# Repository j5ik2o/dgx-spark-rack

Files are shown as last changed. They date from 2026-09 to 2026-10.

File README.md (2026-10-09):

# DGX Spark Rack

DGX Spark本体とACアダプターを置く、3Dプリント用ラックです。**4台専用ラックへの再設計を始めています。** 2列×2段とラック内の交換可能なスイッチ置き場を前提に、リング接続・スイッチ接続の配線は手持ち40cmと当初案の50cmを比較します。[新設計の条件](models/spark-rack/docs/4台専用ラックの設計条件.md)と[従来データの保全](archive/spark-rack-modular-20261009/README.md)を参照してください。

136部品案は不採用です。現在は`mise run overview:spark-rack`で[枠を小型化し、電源4個も内蔵する全体構想](models/spark-rack/docs/凹凸の接合試験片と次案.md)を確認できます。試験片の印刷は後回しです。`mise run joint:spark-rack`は短い接合試験片だけを生成します。梁の取付穴とスイッチ支持板は実測後に設計します。`mise run layout:spark-rack`は[配置の参考](models/spark-rack/docs/仮配置の確認.md)、`mise run build`は従来の3モデル用です。正本は引き続き各モデルの`source/`です。

## 何を編集するか

| 現行モデル | 正本（SSoT） | 最初に開く案内 |
|---|---|---|
| Spark本体ラック | [source内のPythonコードと寸法定義](models/spark-rack/source/) | [本体ラック](models/spark-rack/README.md) |
| ACアダプターラック | [source内のPythonコードと寸法定義](models/adapter-rack/source/) | [アダプターラック](models/adapter-rack/README.md) |
| ファンコンケース | [source内のPythonコード（冒頭に寸法定義）](models/fan-controller/source/freecad_fan_controller.py) | [ファンコンケース](models/fan-controller/README.md) |

3モデルともPythonを正本とし、FCMacroを実行入口にします。ファンコンケースは[共通ドックで両ラックへ取り付ける設計](models/fan-controller/docs/ラックへの取り付け.md)です。実物の取付・強度は未検証です。

## フォルダは用途で分ける

| フォルダ | 入れるもの | 正本として編集するか |
|---|---|---|
| `models/` | 現行モデルの設計コード・CAD正本、参照仕様、モデル別の説明 | `source/`を編集する。`reference/`は購入品の根拠資料 |
| `build/` | 現行モデルから作ったFCStd・STEP・STL・画像・検査結果 | 編集しない。正本から出力する |
| `print-projects/` | スライサーの3MF。配置、材料、ブリム等の印刷設定 | 印刷条件の変更先。形状の正本ではない |
| `archive/` | 旧アダプタースタンド、採用をやめた印刷配置、過去の生成結果 | 現行設計には使わない |
| `tools/` | 複数モデルで使うCAD補助・検査ツール | 共通処理を変更するときだけ編集 |
| `docs/` | リポジトリ全体の運用ルール | 運用を変更するときに編集 |

`exports/`、`design/`、`scripts/`と直下のFCStdは廃止し、上の用途に応じて移動しました。旧スタンドは[archive/adapter-stand-v1](archive/adapter-stand-v1/README.md)にまとめています。

## コマンドで生成する

```sh
mise trust
mise run doctor
mise run build                 # 全モデルのCAD・STL・検査結果
mise run 3mf:prototype:fan-controller     # ケースのCADから、部品別3MFまで生成
```

全モデルの3MFは `mise run 3mf:prototype`。部品・個数の指定と生成先は[タスクランナーの案内](docs/タスクランナー.md)を参照してください。3MFはX1C向けPLA試作設定で、スライス前の状態です。

## レビューを始める

1. 上の表で対象モデルを選び、その案内を開く。
2. `source/`で設計を確認する。各モデルの案内に記載した生成マクロをFreeCADで実行する。
3. `build/<モデル名>/`で形状と検査結果を確認する。印刷設定を確認するときだけ[print-projects](print-projects/README.md)を開く。

生成物は各モデルとも `build/<モデル名>/<実行ID>/` に保存し、Gitには含めません。詳細は[正本と生成物の管理](docs/設計コードと生成物の管理.md)を参照してください。

印刷部品には、外周の面取りとフィレットを設計コードから適用します。[部品別の処理と保護する接合部](docs/面取りとフィレット.md)を参照してください。

## ライセンス

[Apache License 2.0](LICENSE)

Copyright 2026 IDEO PLUS LLC

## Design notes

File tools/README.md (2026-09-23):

# 共通ツール

モデル固有の形状や寸法はここに置きません。現行モデルの設計は [../models/](../models/) を参照してください。

- `cad/freecad_features.py`：拘束付きスケッチと加工の共通処理。
- `cad/check_stl.py`：バイナリSTLの閉じた形状、接続成分、体積、造形寸法を検査。
- `cad/edge_finishing.py`：対象面の凸稜線を選択し、面取り・開口フィレット・寸法変更時の再計算を実施。
- `cad/freecad_mcp.py`：FreeCAD MCPへPythonコードを渡す補助ツール。

- `tasks/cad.py`：miseから呼ぶCAD・3MF生成タスク。
- `tasks/cad_worker.py`：FreeCAD専用プロセスの実行入口。

## ライセンス

[Apache License 2.0](../LICENSE)

Copyright 2026 IDEO PLUS LLC

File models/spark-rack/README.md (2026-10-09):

# Spark本体ラック

**136部品案は不採用です。** 現在は[枠を小型化し、電源4個も内蔵する全体構想](docs/凹凸の接合試験片と次案.md)を検討しています。`mise run overview:spark-rack`で新旧比較の画面を生成します。試験片の印刷は後回しです。`joint:spark-rack`または`structure:spark-rack`は短い試験片だけを生成し、全体の造形用データは生成しません。

[設計条件](docs/4台専用ラックの設計条件.md)と[配置参考](docs/仮配置の確認.md)を参照してください。配置参考の下段高さと制御ケース位置は次案の共通定義へそろえ、未測定の横ずれは製造穴に採用しません。

以下は従来の連結式ラックの操作案内です。[従来データは一式保全済み](../../archive/spark-rack-modular-20261009/README.md)です。

**正本は `source/` のPython設計コードと寸法定義です。**

| 用途 | ファイル |
|---|---|
| 寸法・隙間 | [spark_rack_parameters.py](source/spark_rack_parameters.py) |
| 部品形状・組立配置 | [freecad_spark_rack.py](source/freecad_spark_rack.py) |
| FreeCADで生成 | [run_spark_rack.FCMacro](source/run_spark_rack.FCMacro) |
| 検査 | [validate_spark_rack.py](source/validate_spark_rack.py) |

出力先は `build/spark-rack/<実行ID>/`。FCStd・STEP・STL・画像・検査結果・manifestを保存します。旧FCStdを読み込まず、Pythonの形状定義から生成します。生成FCStdの寸法表は生成時の記録で、編集によって形状が連動するものではありません。変更はPythonへ反映して再生成してください。

現在の接合隙間は0.30mm、ファンは140mmです。0.20mmへの変更は今回のコード移行に含みません。実物の強度・冷却は別途確認が必要です。

[印刷設定](../../print-projects/README.md) と [移行前データ](../../archive/spark-rack-fcstd-v1/README.md) は別管理です。

新版の側板にはファンコン用M4穴を追加しています。`controller_dock.stl` を介して、各ファンのケースをラック外側へ固定します。[取付位置と金具](../fan-controller/docs/ラックへの取り付け.md)を参照してください。旧側板を使用する場合は追加穴加工または新版への交換が必要です。

前面は幅210mmのフレームと外形を揃え、側枠と同じ幅12mmの外周をファン保持部へ一体化しています。高さ162mmの前面枠は、170mmの側枠に対して上下4mmずつ内側です。ファン取付穴・送風開口・保持部の接合位置は維持しています。

## ライセンス

[Apache License 2.0](../../LICENSE)

Copyright 2026 IDEO PLUS LLC

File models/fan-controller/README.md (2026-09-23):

# ファンコンケース

**正本は [source/freecad_fan_controller.py](source/freecad_fan_controller.py) です。** 冒頭の寸法・設定と、それに続く形状コードを編集します。

| 用途 | ファイル |
|---|---|
| 寸法・形状の編集 | [freecad_fan_controller.py](source/freecad_fan_controller.py) |
| FreeCADで生成を実行 | [FanControllerCase.FCMacro](source/FanControllerCase.FCMacro) |
| FCStd・STEP・STL・検査結果の出力 | [build_fan_controller.py](source/build_fan_controller.py) |
| プレビュー画像の生成 | [render_preview.py](source/render_preview.py) |

FreeCADでマクロを実行すると、`build/fan-controller/<実行ID>/` に新規出力します。FCStdとSTEPは組立座標、STLは本体を底面下・蓋を天面下・独立押さえを平置きにして原点へ接地した座標です。`manifest.json` が成功状態であることを確認してください。出力はGit管理対象外です。

## 基板の固定：本体側のねじ留め押さえ

試作で折れた蓋の薄板（厚さ0.9mm・長さ15.07mm）は廃止しました。厚さ3mmの独立押さえを本体の着座ポケットにねじ留めし、基板の縁へ0.8mm掛けます。基板の受け位置・高さは従来どおりです。ねじの締付けは着座面で受け、基板上面には0.20mmの遊びを残します。基板への穴あけは不要です。

| 部品 | ケース1組の必要数 |
|---|---:|
| `CaseBody.stl` | 1 |
| `CaseLid.stl` | 1 |
| `PCBClamp.stl` | 4（同形。反対側は180度回転して組み付け） |
| 呼び径2mm×8mmの樹脂用ねじ | 蓋4本＋押さえ4本＝8本 |

押さえ用ねじ頭は外径4mm以下・高さ1.6mm以下を想定しています。下穴1.6mmは仮値で、使用するねじと印刷材料で確認してください。M4ラック用ねじとは別です。

組立は、基板を受けまで入れる → 押さえ4個を着座面に置く → 各1本のねじで固定 → 蓋を取り付ける、の順です。蓋ねじの位置を変更しているため、本体・蓋は今回生成した組を使います。旧版との混用はできません。

CADでは単一ソリッド、基板・本体・蓋・端子台との干渉、着座面、ねじ頭・ドライバーの空間、上からの着脱を検査します。基板縁の部品・はんだと押さえの実物適合、折れにくさ、繰り返し締結の強度は未検証です。既定の3MF生成は各種類1個なので、押さえ4個を作る場合は `mise run 3mf:prototype:fan-controller -- --part PCBClamp --copies 4` を使います。

プレビューはFreeCAD対応Pythonとmatplotlib・numpyのある環境で `render_preview.py <今回の出力フォルダ>` を実行します。現在の正本から生成するため、同じ設計版の出力先を指定してください。画像は補助資料で、形状の正本ではありません。

元の `designs/fan-controller/FanControllerCase.FCMacro` の形状コードはそのままPythonへ移しました。元マクロ、既存プレビュー、過去の検査記録は [取り込み時のアーカイブ](../../archive/fan-controller-import/README.md) に保全しています。元worktreeは変更していません。今後の編集先はこの `source/` です。

USB-Cは今回の実測値に反映済みです。端子台の逃げ、ファン・温度センサー開口には未修正の箇所が残ります。実物の適合・操作性は未検証です。

## ラックへの取り付け

ケース底部の外側に取付耳を設け、M3穴ピッチ92mmで共通ドックへ固定します。箱本体81.4×39.4mmに対し、耳を含む長さは100mmです。本体ラックは `controller_dock.stl`、アダプターラックは `accessory_plate.stl` として同じドック形状を出力します。[取付方法と必要金具](docs/ラックへの取り付け.md)を参照してください。

## ライセンス

[Apache License 2.0](../../LICENSE)

Copyright 2026 IDEO PLUS LLC

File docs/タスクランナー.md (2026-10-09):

# CADと3MFをコマンドで生成する

`mise`、FreeCAD、Bambu Studioを使います。macOSの `/Applications` にインストールした環境で動作確認しています。初回はリポジトリのルートで `mise trust`、続けて `mise run doctor` を実行します。

## 使うコマンド

| コマンド | 出力 |
|---|---|
| `mise run build` | 全3モデルのFCStd・STEP・STL・検査結果・manifest。ラックは配置画像も生成 |
| `mise run build:spark-rack` | 本体ラックだけを生成・検査 |
| `mise run build:adapter-rack` | アダプターラックだけを生成・検査 |
| `mise run build:fan-controller` | ケースだけを生成・検査 |
| `mise run 3mf:prototype` | 全3モデルをCADから再生成し、部品別の3MFを作成 |
| `mise run 3mf:prototype:spark-rack` | 本体ラックのCADと3MFを生成 |
| `mise run 3mf:prototype:adapter-rack` | アダプターラックのCADと3MFを生成 |
| `mise run 3mf:prototype:fan-controller` | ケースのCADと3MFを生成 |
| `mise run test` | タスクの入力検査・失敗時の扱いを検査 |

**`3mf:prototype` はCAD生成を含みます。先に `build` を実行する必要はありません。** 全モデルのタスクは順番に実行します。FreeCADのGUIが起動しますが、通常終了後に閉じます。途中で失敗した場合はタスクもエラーで終了します。

生成先は次の2か所です。毎回新しい実行IDを使い、既存ファイルは上書きしません。

- CAD：`build/<モデル名>/<実行ID>/`
- 3MF：`print-projects/<モデル名>/<用途>/generated/<実行ID>/`

どちらも自動生成フォルダはGit管理対象外です。3MF側のmanifestに、元のCAD実行ID・STLハッシュ・プロファイルのハッシュ・検査結果を保存します。既存の手調整済み3MFはそのまま保全します。生成後に調整して採用した3MFは、`generated/` の外の同じ用途のフォルダへ別名保存してください。

## 部品と個数を指定する

既定は**試験片を含む全種類を、1種類につき1個ずつ別の3MF**にします。組立1台分の部品数ではありません。必要な数は各モデルの部品表で確認してください。ピンと大型部品は別ファイルになります。

```sh
# ケースの蓋を2個。CADは先に自動生成する
mise run 3mf:prototype:fan-controller -- --part CaseLid --copies 2

# 既に生成・検査したSTLを使う（日時部分は実際の出力先に置き換える）
mise run 3mf:prototype:spark-rack -- --build-dir build/spark-rack/実行ID --part locking_pin --copies 6
```

`--build-dir` は指定モデルの成功した出力だけを受け付けます。設計コードや生成物のハッシュが変わっていれば停止するので、再生成してください。失敗した実行のmanifestは `failed` になります。

## 試作用3MFの印刷設定

共通の[PLA試作用プロファイル](../print-projects/profiles/pla-prototype.json)を使います。プリンターはX1 Carbon・0.4mmノズル、材料はBambu PLA Basic、プレートはTextured PEI、積層0.20mm、壁4周、インフィル20%、外側ブリム5mmです。Bambu Studioに同梱された設定を継承するため、アプリ更新で既定値が変わることがあります。生成した3MFに実際の設定が保存されます。

これは**スライス前のプロジェクト3MF**です。G-code生成・プリンター送信は行いません。Bambu Studioで開いて、必要なサポート・向き・プレート配置・個数・実際のフィラメント割り当てを確認してからスライスしてください。本番素材への変更は別途必要です。CLIの自動配列は使いますが、自動回転は無効にしてCADで設定した造形方向を保持します。

3MF生成にはBambu Studio公式の `--load-settings`、`--load-filaments`、`--export-3mf` を使っています。[公式CLI説明](https://github.com/bambulab/BambuStudio/wiki/Command-Line-Usage)

## インストール先が異なる場合

次の環境変数で変更できます。互換性のあるFreeCADのPython・ライブラリを組にして指定してください。GUIを利用するため、ディスプレイのない環境では追加の対応が必要です。

| 変数 | 既定値 |
|---|---|
| `FREECAD_PYTHON` | `/Applications/FreeCAD.app/Contents/Resources/bin/python` |
| `FREECAD_LIB` | `/Applications/FreeCAD.app/Contents/Resources/lib` |
| `BAMBU_STUDIO` | `/Applications/BambuStudio.app/Contents/MacOS/BambuStudio` |
| `BAMBU_PROFILES` | `/Applications/BambuStudio.app/Contents/Resources/profiles/BBL` |

`mise`を使わない場合も `python3 tools/tasks/cad.py build spark-rack` や `python3 tools/tasks/cad.py 3mf fan-controller --purpose prototype` で同じ処理を実行できます。

## 4台専用ラックの仮配置を生成する

136部品案は不採用です。`mise run joint:spark-rack`または`structure:spark-rack`は、`build/spark-rack/joint-coupons/<実行ID>/`へ短い接合試験片だけを生成します。[次案と試験片](../models/spark-rack/docs/凹凸の接合試験片と次案.md)を参照してください。旧案の明示的な履歴再生成は`python3 archive/spark-rack-structure-rejected-20261009-172152/source/build_four_node_structure.py --historical`で、出力を`archive/build-history/`へ分けます。旧案を印刷しません。

4台専用ラックの配置を検討するときは、`mise run layout:spark-rack`を使います。`build/spark-rack/four-node-layout/<実行ID>/`へ調整画面、配線計算、3方式の参照モデルを生成します。これは印刷部品を含まない配置模型で、3MF生成の入力には使いません。[仮配置の確認](../models/spark-rack/docs/仮配置の確認.md)を参照してください。

## 本番用の生成

`mise run 3mf:production:<モデル名>`（全モデルは `mise run 3mf:production`）を使います。用途を省略した旧 `3mf` タスクは廃止しました。CADの `build` タスクは共通です。

本番設定は未登録です。決定した素材と印刷条件をBambu Studio用JSONに保存し、`print-projects/profiles/production/<モデル名>.json` に次の項目を記載してください。試作用PLA設定への自動代替はしません。

- `process_profile`：印刷条件JSONへのパス（リポジトリ直下基準、絶対パスも可）。
- `filament_profile`：採用するフィラメントJSONへのパス。同じパス基準。
- `expected_settings`：生成3MFで照合する値。`printer_settings_id`（現在の対応機種は `Bambu Lab X1 Carbon 0.4 nozzle`）、`filament_type`（素材名の配列）、`curr_bed_type`、`layer_height`、`wall_loops` が必須。素材以外はBambu設定と同じ文字列型。追加の設定項目も照合できます。

出力先は `print-projects/<モデル名>/production/generated/<実行ID>/` です。manifestにも用途を記録します。本番用という区分は実物の適合・強度・冷却の検証完了を意味しません。

## 電源も内蔵する全体構想を確認する

`mise run overview:spark-rack`で、小型化した共通枠と電源4個の統合配置を生成します。出力は`build/spark-rack/candidate-overview/<実行ID>/`で、旧構想との比較、3配置の表示、外形箱と仮配線の検査結果を含みます。製造形状・造形用ファイルは生成しません。

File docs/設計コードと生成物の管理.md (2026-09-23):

# 正本と生成物の管理

現行モデルの入口は [README](../README.md) の3行の表です。**形状を変えるときは `models/<モデル名>/source/`、印刷条件を変えるときは `print-projects/<モデル名>/<prototype または production>/` を使います。**

## 設計・生成物・印刷設定を混ぜない

```text
models/
  spark-rack/
    source/        本体ラックの正本Python・寸法定義・FCMacro
    docs/          本体ラックの操作・試作ガイド
  adapter-rack/
    source/        アダプターラックの正本Python、寸法定義、FCMacro
    reference/     購入品の仕様と出典
    docs/          アダプターラックの設計・組立ガイド
  fan-controller/
    source/        ケースの正本Python・FCMacro・生成処理
build/
  spark-rack/      正本Pythonから実行ごとに生成するファイル
  adapter-rack/    正本Pythonから実行ごとに生成するファイル
  fan-controller/ 正本Pythonから実行ごとに生成するファイル
print-projects/
  spark-rack/      prototype/ は試作、production/ は本番の印刷設定3MF
archive/
  adapter-stand-v1/ 旧スタンドのコード・資料・保存済み生成物
  print-projects/   失敗した混在配置や変更前のバックアップ
  build-history/    整理前のローカル生成履歴
  layout-history/   整理前のリポジトリ説明
tools/cad/         共通のCAD補助・検査処理
docs/              リポジトリ全体の運用ルール
```

`reference/`の実測値は設計寸法の根拠です。設計へ採用する値はPythonの寸法定義を編集します。FCMacroは実行の入口で、形状定義はPythonへ置きます。

## 本体ラックとファンコンケースもPythonから生成する

本体ラックは `models/spark-rack/source/run_spark_rack.FCMacro`、ファンコンケースは `models/fan-controller/source/FanControllerCase.FCMacro` をFreeCADで実行します。各モデルの `build/<モデル名>/<実行ID>/` に出力します。

本体ラックの旧FCStd・生成物は `archive/spark-rack-fcstd-v1/`、ケースの取り込み前マクロ・画像・検査記録は `archive/fan-controller-import/` に保全しています。現行コードはこれらを読み込みません。本体ラックの生成FCStdの寸法表は生成時の記録です。ケースの寸法定義は正本Pythonの冒頭にあります。

## アダプターラックはPythonから生成する

FreeCAD GUIで `models/adapter-rack/source/run_adapter_rack.FCMacro` を実行します。編集後のモジュールを読み直し、新しい文書を作成して `build/adapter-rack/<実行ID>/` に出力します。

Pythonコンソールから実行する場合は次のとおりです。

```python
from pathlib import Path
import sys

root = Path("/このリポジトリの絶対パス")
sys.path.insert(0, str(root / "models/adapter-rack/source"))
from build_adapter_rack import build
output = build()
```

FreeCADと対応するPython環境が必要です。画像生成を省く `build(render_images=False)` もGUIモジュールを使います。生成したFCStdの寸法表で試した値を採用するときは、正本のPythonへ戻して再生成します。

出力フォルダに成功状態の `manifest.json` があることを確認してください。manifestにはFreeCAD版、入力ソースと生成物のSHA-256を記録します。失敗した実行フォルダは診断用で、印刷に使いません。同じコードでも保存日時等でバイナリが変わるため、再生成の比較には部品体積・寸法などの幾何情報も使います。

`build/` は3モデルともローカル出力としてGit管理対象外です。旧スタンドを再生成する場合はアーカイブ内の入口を使い、出力も `archive/build-history/adapter-stand/` に置きます。現行の `build/` へ旧モデルを混ぜません。

## 印刷設定と旧版を扱う

3MFは形状の正本ではなく、造形方向・個数・フィラメント・ブリム等の記録です。現行のファイルと用途は [print-projects/README.md](../print-projects/README.md) に記載します。モデル更新後も3MFは自動更新されません。

採用しなくなったモデルは、コード・仕様資料・説明・保存済み生成物をまとめて `archive/` へ移します。旧モデルを現行の生成スクリプトや参考パラメーターとして暗黙に参照しません。共通CAD処理だけは `tools/cad/` を利用します。

過去の検査記録やmanifestに残る移動前のパスは、当時の記録として保持します。現行のリンク・生成処理・新しいmanifestは新配置を使います。今回の整理前の説明は `archive/layout-history/`、ローカル生成結果は `archive/build-history/` に退避しています。

## 検証の範囲

各モデルの検査結果には実施した検査だけを記録します。ケースではCAD形状、本体と蓋の干渉、再読込、STLの閉じた形状を検査します。実物の適合・耐荷重・耐熱・冷却性能は別に試作で確認します。

埋め込みPythonの終了時にQtがクラッシュする環境のため、検証プロセスでは文書を閉じて即時終了する回避策を使っています。回避策は設計コードには含めていません。通常の入口はFreeCADアプリ内のFCMacroです。

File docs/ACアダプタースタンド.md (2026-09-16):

# ACアダプターを浮かせる開放スタンド

[DGX-SPARK-ADAPTER-STAND-v1.FCStd](../DGX-SPARK-ADAPTER-STAND-v1.FCStd)は、本体ラックの横に置く独立したスタンドです。アダプターの底面を30 mm持ち上げ、前後2本の桟で支えます。天井と側面は開放し、最初はファンを付けません。

**DGX Spark純正電源「Delta ADP-240LB B」の公開実測値を設計基準にしています。** 電源外形は幅99.05 × 長さ98.99 × 厚さ35.17 mm、左右の余裕は片側1.5 mmです。DGXラックとは独立したFreeCAD文書です。

[2台配置](../exports/adapter-stand/two_units.png)／[スタンドだけを見る](../exports/adapter-stand/stand_only.png)／[4台配置](../exports/adapter-stand/four_units.png)

## 調査した仕様

| 項目 | 確認できた内容 |
|---|---|
| 対象 | NVIDIA DGX Spark付属の純正240W電源 |
| 製造元・型番 | Delta Electronics / ADP-240LB B |
| 公開実測の外寸 | 長さ98.99 × 幅99.05 × 厚さ35.17 mm |
| 公開実測の重量 | 約542.3 g |
| AC入力 | 本体はC6端子、電源コード側は着脱式C5コネクター |
| 出力 | 固定USB-Cケーブル。記事では約180 cm |
| 入出力の配置 | 写真で反対側の面にあることを確認 |

[NVIDIAの公式仕様](https://docs.nvidia.com/dgx/dgx-spark/hardware.html)は付属電源が240Wであることを示しています。型番・外寸・重量は[ChargerLABの実測・分解記事](https://www.chargerlab.com/teardown-of-the-nvidia-dgx-spark-original-240w-usb-c-power-adapter)で確認しました。[全体写真](https://www.chargerlab.com/wp-content/uploads/2026/06/2026061210471560.jpg)ではAC入力と固定USB-Cケーブルが反対側にあります。

外寸はメーカーの公差付き図面ではなく、公開記事の実測値です。これを設計基準に採用し、ユーザーによる採寸を前提とした待ち状態を解消しました。調査日と出典は[adapter_spec.json](../exports/adapter-stand/adapter_spec.json)に記録しています。印刷後の実機適合や耐熱性はまだ試していません。

NVIDIAはACアダプターを通風のある場所で使うよう指定しています。30 mmの持ち上げ高さは今回の設計値で、メーカーが指定した離隔ではありません。[NVIDIA公式ガイド](https://docs.nvidia.com/dgx/dgx-spark/compliance.html)

## 使う部品

| 印刷部品 | 2台分 | 4台分 | 役割 |
|---|---:|---:|---|
| saddle | 4 | 8 | 前後の支持台。左右の低い縁で横ずれを抑える |
| rail | 4 | 8 | 底レール。前後の支持台をつなぐ |
| locking_pin | 8 | 16 | 支持台と底レールの位置を固定 |
| join_clip | 2 | 6 | 隣のスタンドを横に連結 |

通常の組立に金属ねじ・ナットは使いません。固定ピンも印刷部品です。ケーブルの保持に使う結束バンドなどは別途用意します。

外形は、電源の参照外形を含めて2台で約264.1 × 139.0 × 65.2 mm、4台で約536.2 × 139.0 × 65.2 mmです。床から電源底面まで30 mm、左右の余裕は片側1.5 mmです。前後の桟は中心間約64.3 mm、幅12 mmなので、底面の約76%は支持桟で覆われません。この面積は外形からの計算で、冷却効果の測定値ではありません。

## 組み立てる

1. 底レール2本を平行に並べ、前後の支持台を上から差し込みます。レールのピン穴と支持台の穴をそろえます。
2. 4本の固定ピンを上から差し込みます。1台分の支持台は同じ形を前後に、底レールは同じ形を左右に使います。
3. 2台目以降を横に並べ、隣り合う内側レールの穴へ横連結クリップを2個差し込みます。
4. AC入力を手前（−Y）、固定USB-Cケーブルを奥（＋Y）に向けて載せます。支持台が端子側の面を塞がない配置です。前後のレール端にある4 × 12 mmの穴は、結束バンドなどの固定用です。ケーブルには余裕を残します。

アダプターは上へ持ち上げて外せます。載せたまま持ち運ぶための拘束は設けていません。接地面の滑り、接合の緩み、支持台のたわみは実物で確認してください。

## 後からファンを付ける場所

横一列の左右外端にあるレールの中央に、M4用の取付穴を2個設けています。穴径4.5 mm、中心間28 mm、底側のナット座は対辺7.5 mm・深さ3.5 mmです。

**28 mmは、将来のファン用ブラケットをレールへ固定する寸法です。ファン本体を直接取り付ける穴ピッチではありません。** ファン、ガード、ブラケットは今回のモデルに含めていません。必要になったら、広い面に沿って横から送風するブラケットを作ります。内側レールの同じ穴は、横連結クリップが使います。

## FreeCADで寸法を変更する

寸法表の先頭の青いセルを編集します。スケッチ・加工・部品の配置が式で連動します。

| セル | パラメーター | 初期値 |
|---|---|---:|
| B2 | AdapterWidth | 99.05 mm |
| B3 | AdapterLength | 98.99 mm |
| B4 | AdapterHeight | 35.17 mm |
| B5 | LiftHeight | 30 mm |
| B6 | SideGap | 1.5 mm |
| B7 | ModuleGap | 8 mm |
| B8 | FitClearance | 0.3 mm |

ファイルは最初の2台を表示した状態で保存しています。「アダプター3」「アダプター4」と「横連結_2と3」「横連結_3と4」を表示すると4台配置になります。「部品原型_通常は非表示」は非表示のままにします。

## 確認できた範囲と印刷用データ

17枚のスケッチの完全拘束、各部品の閉じた形状、2台・4台配置の干渉、外寸変更の連動、保存後の再読込を確認しました。公開実測値に基づく電源外形を含めたCAD干渉は0.001 mm³を超えるものがありませんでした。

両端の外側40 mm、幅と上下に各10 mmの配線用余白も、CAD上で部品と干渉しないことを確認しています。これは設計上の余白で、コネクターの実形状やメーカー指定の曲げ半径を表したものではありません。

印刷用データは[stl](../exports/adapter-stand/stl)の4種類です。単位はmm、最大寸法は約139 mm、各部品のXYZ最小値は0です。支持台は広い面を下、底レール・固定ピン・横連結クリップは平らな面を下にしています。スライサーで穴の橋渡し、造形方向、必要なサポートを確認してください。

このSTLは公開実測値に基づく設計です。造形後の実機適合、荷重、樹脂の耐熱、温度低下は未検証です。材質は既存ラックと同じASAを候補としますが、実物の温度と荷重を確認して採用します。

記録は[CAD確認](../exports/adapter-stand/validation.json)と[STL確認](../exports/adapter-stand/stl_validation.json)です。再作成用の入口は[scripts/run_adapter_stand.FCMacro](../scripts/run_adapter_stand.FCMacro)で、既存ファイルへの上書きは行いません。

次は1台分をスライスし、接合と載せた状態を試作で確認します。

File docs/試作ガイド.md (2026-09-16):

# DGX Sparkラック：まず接合部を試作する

このモデルは、X1-Carbonで印刷して組み立てるための設計試作です。**最初は接合用の小さな試験片を印刷し、適合を確認してから1台分を作ります。** 実機の足・通気口・配線との適合、長期荷重、冷却性能はまだ確認していません。

初回は「FreeCADモデルを開く」から「1台分を組み立てる」までを読み、増設と寸法変更の節は必要になったときに参照してください。

## FreeCADモデルを開く

[DGX-SPARK-RACK-FREECAD-v1.FCStd](../DGX-SPARK-RACK-FREECAD-v1.FCStd)をFreeCADで開きます。4台構成と印刷部品12種類を含む全体モデルです。寸法表は参考用で、値を書き換えても部品の形状は連動しません。

[1台](../exports/freecad/single.png)、[縦2台](../exports/freecad/two_vertical.png)、[横2台](../exports/freecad/two_horizontal.png)、[4台](../exports/freecad/four_units.png)の配置画像を参照できます。表示と編集の方法は[操作ガイド](FreeCAD版の操作.md)にまとめています。

金色はDGX Sparkの外形参照です。ファン、ワイヤーガード、つまみねじは購入部品の参照形状で、STLには含めていません。緑色はピンとクリップを見分けるための表示色で、これらも同じ黒色のASAで印刷できます。

印刷には[exports/freecad/stl](../exports/freecad/stl)の個別STLをBambu Studioへ読み込みます。座標の単位はmmです。

## 電源を外に置き、1台ごとにファンを設ける

収納するDGXは初期2台、最終4台です。各ユニットは独立して使え、上下の位置決めピンと左右のクリップを追加して連結します。設置面積の上限は設けず、電源アダプターは別置きにします。移動時はDGXを外す運用です。

フレーム本体の初期寸法は幅210×奥行230×高さ170mmです。つまみやガードの突出、上下の4mmの間隔はこれとは別で、組立全体の外形は[manifest.json](../exports/freecad/manifest.json)の`assembly_dimensions_mm`に記録しています。背面には100mmの配線用余白を仮に置いていますが、これはメーカー指定の曲げ半径や必要離隔ではありません。

本体の参照寸法は150×150×50.5mmです。支持棒の上面を床から60mmとし、ファンの中心高さ85mmに本体の中心をほぼ合わせました。模型上でファンの後端から本体前面までは25mmあります。この間隔で十分冷えるかは実機で確認します。

## 小さな試験片で隙間を選ぶ

想定材料はASAです。X1-Carbonに対応するフィラメントの製品別プロファイルを使い、メーカーの乾燥・換気条件に従ってください。ここでは材質名から強度や連続使用温度を保証していません。

1. `fit_coupon_020.stl`、`fit_coupon_030.stl`、`fit_coupon_040.stl`、`bar_coupon.stl`、`locking_pin.stl`を印刷します。数字は接合面の片側の隙間で、順に0.20、0.30、0.40mmです。モデルの初期値は0.30mmです。
2. 短い支持棒を各試験片に差し込み、上から固定ピンを通します。手で組み立てられ、抜き差しで割れず、大きなガタがない組み合わせを選びます。きつい場合は無理に押し込まず、FreeCADで接合部の形状を調整し、対象部品のSTLを書き出し直します。
3. `hardware_coupon.stl`と`stack_locator.stl`で、購入する金具と上下のピンも確認します。長方形の試験片を幅96mmの向きで見ると、左からM4穴径4.3／4.5／4.7mm、六角穴の対辺7.3／7.5／7.7mmです。もう一列の丸穴は径6.4／6.6／6.8mmで、径6mmの上下ピンを試します。

保存済みの部品別STLは、側板の外面が上を向いています。Bambu Studioで側板を裏返し、差込口のない外面を造形面へ向けてください。支持棒は平置き、固定ピンは頭を下にした向きです。ファン保持部の腕や横穴については、断面・オーバーハング表示を見てサポートを設定してください。最終的なスライスと造形は未実施です。

## 1台分を組み立てる

| 印刷部品 | 1台分 | 役割 |
|---|---:|---|
| side_L / side_R | 各1 | 左右の側板 |
| crossbar | 3 | 下の2本で本体を支え、上の1本でフレームをつなぐ |
| locking_pin | 6 | 支持棒と側板の接合を固定 |
| fan_cassette | 1 | 前から取り外せるファン保持部 |

購入部品は、140mm PWMファン1基、対応するワイヤーガード1枚、ファン固定具4か所分、M4×60のつまみねじ2本、M4ナット2個を想定しています。つまみねじはねじ部60mm・頭部径16mm以下、ナットは対辺7mm・厚さ3.2mmを初期モデルとしています。購入品の寸法と試験片の適合を確認してください。ねじ山、ガードの細部、防振部品は参照モデルに厳密には再現していません。

1. 左右の側板の差込口に3本の支持棒を入れ、6本の固定ピンを上から通します。棒は3本とも同じ形です。
2. 前柱の後側に開いた六角穴からM4ナットを入れます。前側の座面まで押し込み、ねじを締めるまでは後ろから保持します。
3. ファンとワイヤーガードをファン保持部へ取り付けます。取付穴の中心間距離は124.5×124.5mm、穴径は4.5mmです。ファン側の固定具に合わせて穴と厚さを確認します。
4. 保持部の下の突起を側板の穴へ差し込み、前から2本のつまみねじを締めます。ねじの頭は前面に出してあるので、取り外すときも前から操作します。
5. 本体と同程度の重さ・接触条件のダミー荷重で、たわみ、接合の緩み、保持部の振動を確認します。異常があれば実機を載せる前に断面や接合を修正します。

実機を載せる段階では、足が2本の支持棒に掛かること、通気口を塞がないこと、背面の全端子にコネクターを挿せることを確認します。模型は足や端子を再現していません。支持位置が合わない場合は、全体モデルの支持棒の配置と側板の差込口を両方調整します。

## ファンは外部電源と手動ダイヤルで調整する

候補はNoctua NF-A14x25 G2 PWMです。ファン本体140×140mm、厚さは防振パッド込み27mm、取付ピッチ124.5mmの公表寸法を使用しています。[Noctua公式仕様](https://www.noctua.at/en/products/nf-a14x25-g2-pwm/specifications)

電源はNV-PS1、手動PWMコントローラーはNA-FC1を候補とします。接続の考え方は次のとおりです。

```text
NV-PS1 → NA-AC10 → NA-FC1 → PWM分岐 → 各ユニットのファン
```

NV-PS1は12V・最大24Wです。ファン4基の公表最大電流の合計は0.76A、消費電力は9.12Wで、ファン分は電源とコントローラーの定格内です。分岐・延長ケーブルも各製品の定格と端子配置を確認してください。NA-FC1付属の3分岐だけでは4基を接続できないため、追加分岐が必要です。[電源の公式説明](https://www.noctua.at/en/products/nv-ps1)、[コントローラーの公式説明](https://www.noctua.at/en/products/na-fc1)

NA-FC1単体は温度による自動調整をしません。通常時と高負荷時の回転数はダイヤルで変更します。初めはファン本体の風向表示とDGXの実際の吸排気方向を確認し、矛盾しない向きに取り付けてください。

室温と処理負荷をそろえて、ラックに置かない場合、ラック＋追加ファン停止、追加ファン運転を比較します。温度、処理速度、本体ファンの音、ラック側ファンの音、フレームの変形を記録して、配置と回転数を決めます。今回のモデル生成では熱解析や温度測定はしていません。

## 2台・4台へ増設する

| 配置 | 基本ユニット数 | 追加する上下ピン | 追加する横クリップ |
|---|---:|---:|---:|
| 2台縦 | 2 | 4 | 0 |
| 2台横 | 2 | 0 | 2 |
| 4台、2段×2列 | 4 | 8 | 4 |

上下ピンの中央のつばが、段間の4mmの隙間を作ります。横クリップは隣接する側板2枚を上からまたぎます。これらは設置中の位置決め用で、機器を載せた状態で運搬するための固定具ではありません。

2段にする前に、下段フレームが上段のユニットと本体の荷重を受ける状態をダミー荷重で確認します。1台分だけの確認では、2段全体の荷重確認を済ませたことにはなりません。

## 形状を変更して書き出す

全体モデルで編集する場合は、対象のソリッドを選んで加工や配置を変更します。参考用の寸法表には形状を制御する式がないため、関連する部品も確認してください。比較試験用の部品モデルは削除しているので、全体モデル内の部品を使います。

変更したFCStdを保存し、印刷する部品だけを選択してFreeCADからSTLを書き出します。単位をmmとし、Bambu Studioで造形方向と外形寸法を確認します。保存済みの12種類のSTLを検査するコマンドは次のとおりです。

```sh
python3 scripts/check_stl.py exports/freecad/stl --output exports/freecad/stl_validation.json
```

この検査スクリプトは、最小座標が0のバイナリSTLを対象にします。GUIから新しく書き出したSTLでは、形式と原点を合わせてから使ってください。寸法検査やソリッドの確認だけで、実物の強度、ASAの収縮、冷却効果は保証できません。

## 試作で合わなかった箇所を記録する

この作業の会話に、部品名、使ったSTL、フィラメント、スライス設定、合わなかった寸法を伝えてください。接合部の写真や測定値があれば、次の寸法調整に使えます。

用語：保持部（カセット）はファンを取り付けて前から外す部品、固定ピンは支持棒を留める棒、上下ピンはユニット間の位置決め部品、PWMはファンへ回転速度を指示する信号です。

更新日：2026年9月16日。

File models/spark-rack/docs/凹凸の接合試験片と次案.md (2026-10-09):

# 枠を小型化し、本体と電源を一つの枠へ収める

2026年10月9日17:21の136部品案は不採用です。4台の共通枠、140mmファン4個、既存の共通ドック、電源用120mmファン2個を維持し、部材の端の凹凸へ継ぎ方を改めます。[指定生成物は保全済み](../../../archive/spark-rack-structure-rejected-20261009-172152/README.md)です。旧案の金具一覧と横梁の印刷向きは履歴として残します。

今回造形用に出力するのは短い接合試験片5種類だけです。全体の72個案、ファン保持部、トレー、スイッチ支持板の造形データは作りません。

2026年10月9日のユーザー指定で、試験片の印刷は後回しにします。現物の適合、段差の当たり、ガタは未確認のままです。その間は部材の凹凸と全体の組立順を図面上で検討し、実測が必要な梁の取付穴とスイッチ支持板は保留します。印刷を再開するときは短い試験片から確認します。

## 設計変更後の全体像を見る

```sh
mise run overview:spark-rack
```

`build/spark-rack/candidate-overview/<実行ID>/rack-candidate-overview.html`に全体構想図を生成します。リング接続、CRS812、CRS804の配置を切り替え、斜め・前面・背面・側面・上面から確認できます。斜め表示はドラッグで回転します。

柱と梁は別部品の継ぎ手を取り除いた外形で示し、造形分割の候補線を残しています。角と直線部の接合は、検査済みの短い形状の拡大図を添えました。全長部材への凹凸の統合、全体の組立経路、梁の取付穴、スイッチ支持板は未完成です。この図から造形用ファイルは生成しません。

最新のユーザー指定は、両スイッチの収容を検討しながら余白を詰め、ACアダプターも枠内へ収めることです。共通枠を512×520×420mm、柱の間の幅を456mm、奥行を464mmへ変更しました。枠の短縮は幅8mm・奥行10mmですが、制御ケース6個を内側へ移すため設置幅は618mmから512mmになります。脚は底面から8mm下に示します。リング用の段間隔160mmとスイッチ用220mmは維持します。

電源は既存の正本にある約99×99×35mmを使い、手前下側に2列×2段で仮配置します。ACとUSB-Cの出口を前後へ向け、端子側に各30mmの設計予約を置きます。120mmファン2個は左右に置き、側面へ排気する構想です。電源と本体の間には参考の仕切りを示し、電源の温風を本体の吸気へ直接向けないようにします。支持部の接合、端子の実形状、冷却効果は未確認です。

旧全体構想も比較用に保持し、画面の「案」で切り替えられます。3配置とも機器と枠の外形箱、仮外径10mmの配線経路、電源端子側30mmの予約に干渉がないことを確認しました。ファンの穴や接合形状を含む全体検査ではありません。

生成元は[build_rack_candidate_overview.py](../source/build_rack_candidate_overview.py)と[rack_candidate_overview.html](../source/rack_candidate_overview.html)です。不採用の全体案の形状コードは読み込みません。接合図として参照した試験片の生成記録も、同じ実行の照合記録へ含めます。

全体図の再生成に過去の`build/`は不要です。接合部の参照図は[reference内の保全図](../reference/joint-illustrations-20261009/README.md)、前の案は[archive内の比較データ](../../../archive/spark-rack-overview-20261009-200723/README.md)から明示的に読み込みます。それぞれ元の生成記録と保全時の内容照合記録を添えました。現在の配置はPythonから生成し、比較データを現在の部材の形状として採用しません。

## 柱と梁は段差で受け、ほぞを浮かせる

試験片の外形は28mm角です。梁の根元に8mmの段差を設け、柱の水平な受け面に載せます。奥のほぞは差し込み12mm、幅12mm。この根元とほぞの寸法は固定形状で、調整できる設定には含めません。片側隙間は0.3mmとし、ほぞの下面は受け穴の底から浮かせています。

隣り合う2本の梁の根元は、角の内側を相補的に逃がします。奥のほぞは高さを分け、低いほぞの梁を先に、次に高いほぞの梁を上から入れます。逆の順番では途中でほぞが重なるため、この順序を試験片に明記しました。上側の柱は梁の後に取り付ける構想です。

直線部は二股の端に上へ開いた溝を設け、相手の差し込みを上から落とします。二股の底面で差し込みの下面を受けます。別部品の差し込み金具や外板は使いません。

この試験で確認するのは、受け面の当たり、ほぞや二股のガタ、組み入れる順序です。全体の柱分割位置、リング用とスイッチ用の高さ切替、全体を組み立てる経路、止めねじは未設計です。止める場合は内側か下面のねじ1本に限定し、外へ固定板を追加しません。

## 接合試験片だけを生成する

```sh
mise trust
mise run joint:spark-rack
```

`mise run structure:spark-rack`も現在は同じ試験片だけを生成します。出力先は`build/spark-rack/joint-coupons/<実行ID>/`です。毎回新しいフォルダを作り、既存ファイルを上書きしません。実際のスライスとプリンターへの送信は行いません。

| 造形用ファイル | 数量 | 確認する部分 |
|---|---:|---|
| `column_socket.stl` | 1 | 柱の受け穴と水平な段差 |
| `beam_lower_tenon.stl` | 1 | 先に入れる低いほぞの梁 |
| `beam_upper_tenon.stl` | 1 | 後から入れる高いほぞの梁 |
| `beam_fork.stl` | 1 | 直線部の二股と底面 |
| `beam_drop_blade.stl` | 1 | 二股へ上から入れる差し込み |

差し込み側の梁3種類は、太い端面を造形面へ向けています。短い形状の適合確認用の向きで、全長部材の向きが決まった後は、その向きでも再確認します。材料、収縮、造形面の状態による隙間の変化は実物で確認します。

`joint-coupons.FCStd`と`corner-coupons.step`は接合状態の確認用です。`validation.json`には受け面の面積、干渉、上からの挿入経路と順序を記録します。`stl-validation.json`と`manifest.json`で閉じた形状と、入力・生成物の内容一致も確認できます。

## 72個は電源を内蔵する前の数量目標

旧案の別部品の接続金具32個、角の固定板24個、横梁受け8個を廃止する方針です。柱・梁52個と、トレー、ファン保持部、脚、制御ケース取付部、共通ドック各4個の72個は、電源を内蔵する前の数量目標です。最新案では電源支持部、120mmファン保持部、電源用ドック、仕切りが加わるため、部品数は未確定です。参考外形の数を印刷部品数として扱いません。

未測定の30mm横ずれを梁のファン・トレー取付穴へ固定しません。[未確定値の記録](../reference/pending-mount-measurements.json)に、端子、足、採用する横ずれ、ケーブル条件、スイッチの耳込み幅と奥行を記録する欄を設けました。必要な値が空の間は、製造用の梁穴とスイッチ支持板を生成しない方針です。

CRS812の資料上の本体幅443mmは、耳込み幅ではありません。耳が482.6mmまで伸びる場合、最新案の内のり456mmには入りません。筐体を下から支え、取付耳を外す構想ですが、耳と支持方法が確定するまで支持板を生成しません。奥行268mmと156mmの食い違いも残しています。163.25mmの旧予約穴は次案に使いません。CRS804の公式寸法図は再確認し、筐体奥行360mmと後部の突出を含む387mmを区別しました。収容奥行387mmは維持します。

## 下段高さと制御ケース位置は共通の定義へそろえる

[rack_candidate_datums.py](../source/rack_candidate_datums.py)を次案の共通基準にしました。下段底の設計座標は72mm、本体用制御ケースは側梁の内側へそろえます。配置参考の横ずれは0mmを初期表示とし、端子の30mm偏りは配線評価用の未測定の仮定として残します。採用する取付位置は実測後に決めます。

不採用の136部品案のコードは`archive/spark-rack-structure-rejected-20261009-172152/source/`へ移し、履歴のために保持します。その再生成は明示的な履歴用実行だけに限定し、出力も`archive/build-history/`へ分けます。既存の136個を印刷しません。

## 導風は形状の参考として追加する

`air-guide-preview.FCStd`に、ファン後端の円形開口から本体前面の参考外形へ風を寄せる形状を置きました。入口径132mm、出口の参考内寸154×54.5mm、移行部分は23mmです。140mmファンと124.5mmの取付穴間隔は維持します。

本体前面の通気口は未測定です。この形状は保持部との一体化、取付、風向、圧力損失、冷却を検証したものではなく、造形用ファイルに含めていません。出口を実際の通気口へ合わせてから保持部へ統合します。

用語：段差は梁の重さを受ける水平な面、ほぞは奥へ入る位置決めの突起、二股は相手の差し込みを両側から案内する部材の端です。試作で合わない場合は、試験片名、材料、生成実行ID、段差の当たりとガタの測定値をこの会話へ記録してください。

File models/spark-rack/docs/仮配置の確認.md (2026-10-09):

# 次案の配置参考は共通基準へそろえる

136部品案は不採用です。現在の進め方は[枠を小型化し、電源を内蔵する次案](凹凸の接合試験片と次案.md)を参照してください。配置の参考表示は下段底72mm・制御ケースの内側位置を共通定義へそろえ、本体の横ずれは0mmを初期値にしました。電源の統合配置は`overview:spark-rack`の画面で確認します。未測定の端子位置を製造穴へ固定していません。以下の旧数値表や構造説明は当時の参考で、採用寸法ではありません。

2列×2段と中央段のスイッチに、本体用140mmファン4個を追加しました。120mmの2個は別置きの電源アダプターラック用へ使います。初期案はリング・CRS812・CRS804の3方式とも、仮の端子位置と曲げ条件では40cm内に収まります。ただし、スイッチ端子を筐体の端まで広げた条件では両機種とも40cmを超えます。実端子位置と曲げ条件を確認する前に、配線が届く設計として確定しません。

## 配置検討画面と参照モデルを生成する

FreeCADの実行環境で、リポジトリのルートから実行します。

```sh
mise trust
mise run layout:spark-rack
```

今回の生成先は `build/spark-rack/four-node-layout/<実行ID>/` です。毎回新しいフォルダを作ります。その中の `four-node-layout.html` をブラウザーで開くと、40cm／50cm、ファンの表示、接続方式、見る方向、左右・上下の間隔、引き出し長、曲げ半径を変更できます。「前面」でファン4個を確認でき、詳細欄で端子の仮位置や余裕も調整できます。

画面内の変更は保存済みのFreeCADモデルへ自動反映しません。「検討値を保存」で比較用の値を残し、採用する寸法を正本のPythonへ反映して再生成します。FreeCADを使わず画面と計算だけ生成する場合は、`python3 models/spark-rack/source/build_four_node_layout.py --without-cad` を実行します。

| 生成ファイル | 確認する内容 |
|---|---|
| `four-node-layout.html` | 配置と配線条件を調整する画面 |
| `four-node-layout-ring.FCStd` / `.step` | 4台のリング接続。スイッチと中央の支持範囲を外した表示 |
| `four-node-layout-crs812.FCStd` / `.step` | CRS812を中央段へ載せる仮配置 |
| `four-node-layout-crs804.FCStd` / `.step` | CRS804を中央段へ載せる仮配置 |
| `layout-report.json` | 端子座標、配線中心線、解析式の経路長、余裕、収容・干渉の検査 |
| `validation.json` / `cad-validation.json` | 初期配置の検査と保存後の再読込検査 |
| `manifest.json` | 入力の正本と出力ファイルの内容照合に使う記録 |

参照モデルにある箱は機器やファンコントローラーの収容範囲、薄板は支持範囲、線は配線中心線です。ファンと保持板は開口と公表取付ピッチを含む参考形状で、ガードも外形の範囲だけを示しています。共通枠の梁、接合部、支持板の通風穴、印刷部品を設計したものではありません。

## 初期案は幅520×奥行530×高さ420mm

共通枠の仮収容範囲は幅520×奥行530×高さ420mm、左右のSpark中心間隔は180mmです。当面のリングでは上下中心間隔を160mmへ詰め、下段の本体底を70mm、上段を230mmに置きます。将来のスイッチ接続では上下中心間隔を220mmへ広げ、上段の本体底を290mm、スイッチの端子中心を高さ205.25mmに置く案です。Sparkの背面とスイッチの接続端子面は同じ面です。

ラックを増設する連結構造は設けません。同じ4台用フレームに支持段を移動できる取付位置を用意する方針です。画面で接続方式を切り替えると段間隔の初期値も切り替わります。実物の固定機構は未設計です。

上下段とも140mmのファンを1台につき1個、合計4個配置します。ファンは防振パッド込み厚さ27mm、ファン後端とSpark前面は25mm離す仮定です。保持板はファン外形の各辺へ6mm加えた範囲、厚さ4mmとし、ガードにも4mmの収容範囲を予約しています。

ファンコントローラー4個と共通ドックは、つまみを含む100×44×43mmの収容範囲として左右の側面寄りへ置きました。既存ケースの設計は保持しています。ケースの実形状やねじ、配線・取り外しの操作空間はこの範囲検査だけで確認済みとは扱いません。

ファンを追加する前の段間隔180mmでは、ファンや保持板がスイッチと支持範囲へ重なりました。段間隔を広げ、Sparkの支持範囲を奥行150mmへ縮めた案では、参照機器・保持板・支持範囲の重なりを解消しています。

CRS812の幅とCRS804の最大奥行を収める共通の案です。機種を選んだ後は、その機種に合わせて幅または奥行を詰める余地があります。背面側には110mmの配線空間を予約しています。

Sparkの2つの端子は、本体中心から横へ30mmずれ、端子間隔24mm、本体底からの高さ25.25mmと仮定しました。この仮端子の中心をそろえるため、Sparkの2列全体を枠の中心から30mmずらしています。端子位置を実測すると、この横位置も変わる可能性があります。

## 余長と公称長の基準差を含めて比較する

端子から直線30mmを引き出し、中心線の曲げ半径20mmで2つの四分円を作り、その間を直線でつなぎます。計算した経路長に余長30mmと公称長の測定基準の差に備える40mmを加え、公称長の400mmまたは500mmから差し引きます。すべての曲げ条件と予約量は仮定です。

| 接続方式・条件 | 4経路の最長必要長 | 400mmに対する残り | 500mmに対する残り |
|---|---:|---:|---:|
| リング・段間隔160mm・仮端子 | 312.8mm | 87.2mm | 187.2mm |
| リング・段間隔220mm・比較用 | 372.8mm | 27.2mm | 127.2mm |
| CRS812・仮端子 | 330.9mm | 69.1mm | 169.1mm |
| CRS804・仮端子 | 278.4mm | 121.6mm | 221.6mm |
| CRS812・スイッチ端子を筐体の端まで広げた条件 | 502.2mm | −102.2mm | −2.2mm |
| CRS804・スイッチ端子を筐体の端まで広げた条件 | 401.7mm | −1.7mm | 98.3mm |

厳しい条件の比較は、スイッチ端子の横位置と高さを筐体の左右端・上下端まで広げたものです。Sparkの端子位置は仮定のままで、実機の寸法公差や端子の突出まで検証した値ではありません。

残りが負になる条件は、予約込みの必要長が公称長を超えることを意味します。引き出しや曲げ半径が大きいほど必要長も増えます。たとえば段間隔160mmのリングで、引き出し50mm・曲げ半径30mmとすると最長必要長は364.2mm、40cmの残りは35.8mmです。端子位置とケーブルの型番を確認するまで、この案を実物の配線が届く設計として確定しません。40cmケーブルのスイッチでの電気的な適合も、形状検査とは別に未確認です。

## 検査は配置の計算と参照形状まで

Pythonの検査では円弧の経路長、前後差の影響、曲げ半径を保てない経路の除外、4台の8端子の重複しないリング配線、4つのスイッチ端子への割当、収容範囲、機器と支持範囲の干渉を確認します。参照モデルは形状の妥当性と保存後の再読込を検査します。画面の計算値はPythonの初期案と照合し、条件変更と狭い画面の表示も確認します。

線径、ケーブル同士の干渉、余長の収納、コネクターと取付金具、ケースの実形状と配線・取り外しの操作空間、電源アダプター、通風、実物の耐荷重は今回の検査対象に含みません。これらは配置の実測値を反映してから設計します。ファンの枠・保持板・ガードの収容範囲は干渉検査に含めています。

正本は [four_node_layout.py](../source/four_node_layout.py)、[FreeCADの参照モデル生成](../source/freecad_four_node_layout.py)、[生成入口](../source/build_four_node_layout.py)、[画面の正本](../source/four_node_layout.html)です。購入品の仕様と仮定は [reference/four-node-layout-assumptions.json](../reference/four-node-layout-assumptions.json)に記録しています。[4台専用ラックの設計条件](4台専用ラックの設計条件.md)も参照してください。

電源側は[既存の設計と組立](../../adapter-rack/docs/設計と組立.md)を参照してください。120mmを各列へ1個、合計2個使います。電源側の外形と冷却の検査は、本体側の参照モデルとは別に行います。

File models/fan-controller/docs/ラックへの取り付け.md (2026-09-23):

# ファンコンケースを両ラックへ取り付ける

温度センサー付き基板型ファンコンを、ファン1個につき1個使用します。140mm×2用と120mm×2用はそれぞれ、ファンコン2個・12V 3A電源1個・DC電源二股ケーブル1本の独立した系統です。ケースも合計4個です。分岐するのはコントローラーへのDC電源で、ファンの制御信号ではありません。基板端子台への接続用DCジャック付きケーブルも、各コントローラーに必要です。

## 取付方式

ラック外面 → 一体スペーサー付き共通ドック → ケース底の外側取付耳、の順に固定します。表示窓とつまみは外側を向きます。ケース底内部にねじ頭を突出させないため、基板下面の部品との隙間を減らしません。ドックには通風用の開口を設けています。

| 項目 | 設計値 |
|---|---|
| ドック外形 | 100×43.4mm、板厚8mm＋スペーサー3mm |
| ラック側M4穴 | ピッチ28mm、通し穴4.5mm、頭の座ぐり8.4mm径・4.5mm深さ |
| ケース側M3穴 | ピッチ92mm、通し穴3.4mm、耳の表面に90度皿座ぐり（径6.4mm・深さ1.5mm） |
| ケース取付耳 | 厚さ4mm。ケースの外形長さは耳を含め100mm |
| ドック裏面のM3ナット穴 | 対辺5.8mm、深さ2.8mm |

取付規格は [controller_mount.py](../../../tools/cad/controller_mount.py) で共有します。

## 外観

ドックは外周と通風窓をR4、触れる外周稜線をR0.4に丸めます。ケースの取付耳は先端をR3とし、ケース本体の角丸と揃えます。穴位置・穴径・締結部の厚さは変えません。取付耳は薄い飾り板にせず、4mmの厚さを維持します。

ドックの幅はケース幅39.4mmに対して左右2mmずつ見える43.4mmとし、側辺の幅6mmを維持するよう通風窓も調整します。ラック穴の位置を変えず、ドック内の取付位置を長手中央から42mmずらします。本体ラックではドックがZ=52〜152mmに収まり、支持棒下面と上部開口上端に揃います。アダプターラックでは前端Y=-75mmが前柱の前端Y=-74mmにほぼ揃います。ケースは従来配置より長手方向へ12mm移動するため、旧ドックの位置と混在させず新版の組立図を参照してください。

外観確認用の組立図では、ラックとケースを黒系、ドックを少し明るいチャコール、ファンをベージュで表示します。実際のファンは決定済みのベージュ／ブラウン、印刷部品は黒を想定しています。CADの表示色はフィラメント設定を変更しません。

## 配置と必要数

| ラック構成 | ファン数 | ケース・ドック数 | 配置 |
|---|---:|---:|---|
| 本体ラック1台 | 1 | 各1 | 左外側 |
| 本体ラック縦2台 | 2 | 各2 | 左外側、各段に1個 |
| 本体ラック横2台 | 2 | 各2 | 左右の外側 |
| 本体ラック4台 | 4 | 各4 | 左右の外側、各段に1個 |
| アダプターラック1台／縦2台 | 1 | 各1 | 左前柱の外側 |
| アダプターラック横2台／4台 | 2 | 各2 | 各列の外側前柱に1個 |

横連結する場合、列間の内側には取り付けません。本体ラックはケース長手を縦向き、アダプターラックは横向きに配置します。コントローラー自身の消費電力、電源極性と基板への配線は実機で確認してください。

## 金具と組立

ケース1個のラック取付に、M4×25六角穴付きボルト2本・M4ナット2個、M3×12の90度皿ねじ2本・M3ナット2個を使います。M3の長さ12mmは頭を含み、頭径6mm以下を想定します。皿ねじの頭を耳の表面より沈め、コネクターの配線余白へ出さない構造です。なべ頭・六角穴付きの円筒頭などへの置き換えはできません。これは蓋・基板押さえ用の樹脂用2mmねじとは別です。ドック内へ沈めるM4ねじ頭は径8mm以下・高さ4mm以下が条件です。金具の実物寸法と穴の収まりは試作で確認してください。

1. ドック裏側の六角穴へM3ナット2個を入れます。
2. ケースを載せる前に、ドックをM4×25とM4ナットでラックに固定します。
3. ケースの底部の耳をドックのM3穴に合わせ、外からM3×12の90度皿ねじで留めます。
4. ケースだけを外す際はM3の2本を外します。配線を外し、ケースを外向きに引き抜けます。

本体ラックの新版側板には、各段の底から高さ60mm、前端（Y=38mm）から62mm／90mmの位置に、M4通し穴を設けます。以前に印刷した側板にはこの穴がないため、新版側板への交換または正確な追加穴加工が必要です。アダプターラックは既存の前柱の穴ピッチ28mmをそのまま使い、旧44×48mmの仮プレートを新ドックへ交換します。ケースは取付耳付きの新版が必要です。

ドックはケース接触側の広い面を下にして造形します。STL出力時にこの方向へ揃えています。生成された1種類のドックを、必要個数分印刷してください。

## 検査と限界

各ラックの4構成、合計8構成で、ケース本体・蓋・独立押さえ・取付ボルト・ナットを配置して干渉を検査します。配線用には各開口の外側に30×20×14mmの設計余白を置き、ラック・ケース・ボルト・ナットすべてに対して検査します。ケースの取り外しには外向き30mmの経路を検査します。コネクターの実測外形・曲げ半径・手指の操作空間を保証する値ではありません。

検査入口は [check_controller_mounts.py](../../../tools/cad/check_controller_mounts.py)。FreeCAD対応Pythonにライブラリパスを設定して実行すると、`build/fan-controller/mount-check-<実行ID>/` に組立FCStd・画像・検査結果・manifestを生成します。macOS既定環境では次のコマンドです。

```sh
PYTHONPATH=/Applications/FreeCAD.app/Contents/Resources/lib /Applications/FreeCAD.app/Contents/Resources/bin/python tools/cad/check_controller_mounts.py
```

実物の取付強度・振動・熱・端子への挿しやすさは未検証です。ケース内部の端子台の逃げとファン／温度センサー開口の修正も別途必要です。まず1組で固定と操作性を確認してください。

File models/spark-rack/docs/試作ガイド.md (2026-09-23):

# DGX Sparkラック：まず接合部を試作する

このモデルは、X1-Carbonで印刷して組み立てるための設計試作です。**最初は接合用の小さな試験片を印刷し、適合を確認してから1台分を作ります。** 実機の足・通気口・配線との適合、長期荷重、冷却性能はまだ確認していません。

初回は「FreeCADモデルを開く」から「1台分を組み立てる」までを読み、増設と寸法変更の節は必要になったときに参照してください。

## FreeCADモデルを開く

[生成マクロ](../source/run_spark_rack.FCMacro)を実行し、今回の出力先の `DGX-SPARK-RACK.FCStd` をFreeCADで開きます。4台構成と共通ドックを含む印刷部品13種類のモデルです。寸法表は参考用で、値を書き換えても部品の形状は連動しません。

1台（今回の `build/spark-rack/<実行ID>/` 内）、縦2台（今回の `build/spark-rack/<実行ID>/` 内）、横2台（今回の `build/spark-rack/<実行ID>/` 内）、4台（今回の `build/spark-rack/<実行ID>/` 内）の配置画像を参照できます。表示と編集の方法は[操作ガイド](FreeCAD版の操作.md)にまとめています。

金色はDGX Sparkの外形参照です。ファン、ワイヤーガード、つまみねじは購入部品の参照形状で、STLには含めていません。緑色はピンとクリップを見分けるための表示色で、これらも同じ黒色のASAで印刷できます。

印刷には本体ラックのSTL（今回の `build/spark-rack/<実行ID>/` 内）の個別STLをBambu Studioへ読み込みます。座標の単位はmmです。

## 電源を外に置き、1台ごとにファンを設ける

収納するDGXは初期2台、最終4台です。各ユニットは独立して使え、上下の位置決めピンと左右のクリップを追加して連結します。設置面積の上限は設けず、電源アダプターは別置きにします。移動時はDGXを外す運用です。

フレーム本体の初期寸法は幅210×奥行230×高さ170mmです。つまみやガードの突出、上下の4mmの間隔はこれとは別で、組立全体の外形はmanifest.json（今回の `build/spark-rack/<実行ID>/` 内）の検査記録に記録しています。背面には100mmの配線用余白を仮に置いていますが、これはメーカー指定の曲げ半径や必要離隔ではありません。

本体の参照寸法は150×150×50.5mmです。支持棒の上面を床から60mmとし、ファンの中心高さ85mmに本体の中心をほぼ合わせました。模型上でファンの後端から本体前面までは25mmあります。この間隔で十分冷えるかは実機で確認します。

## 小さな試験片で隙間を選ぶ

想定材料はASAです。X1-Carbonに対応するフィラメントの製品別プロファイルを使い、メーカーの乾燥・換気条件に従ってください。ここでは材質名から強度や連続使用温度を保証していません。

1. `fit_coupon_020.stl`、`fit_coupon_030.stl`、`fit_coupon_040.stl`、`bar_coupon.stl`、`locking_pin.stl`を印刷します。数字は接合面の片側の隙間で、順に0.20、0.30、0.40mmです。モデルの初期値は0.30mmです。
2. 短い支持棒を各試験片に差し込み、上から固定ピンを通します。手で組み立てられ、抜き差しで割れず、大きなガタがない組み合わせを選びます。きつい場合は無理に押し込まず、FreeCADで接合部の形状を調整し、対象部品のSTLを書き出し直します。
3. `hardware_coupon.stl`と`stack_locator.stl`で、購入する金具と上下のピンも確認します。長方形の試験片を幅96mmの向きで見ると、左からM4穴径4.3／4.5／4.7mm、六角穴の対辺7.3／7.5／7.7mmです。もう一列の丸穴は径6.4／6.6／6.8mmで、径6mmの上下ピンを試します。

新しく生成するSTLは、側板の差込口のない外面を造形面へ向けた向きです。支持棒は平置き、固定ピンは頭を下にしています。ファン保持部の腕や横穴はスライサーで断面・オーバーハングを確認し、必要なサポートを設定してください。

## 1台分を組み立てる

| 印刷部品 | 1台分 | 役割 |
|---|---:|---|
| side_L / side_R | 各1 | 左右の側板 |
| crossbar | 3 | 下の2本で本体を支え、上の1本でフレームをつなぐ |
| locking_pin | 6 | 支持棒と側板の接合を固定 |
| fan_cassette | 1 | 前から取り外せるファン保持部 |
| controller_dock | 1 | ラック外側へファンコンケースを固定 |

購入部品は、140mm PWMファン1基、対応するワイヤーガード1枚、ファン固定具4か所分、M4×60のつまみねじ2本、M4ナット2個を想定しています。つまみねじはねじ部60mm・頭部径16mm以下、ナットは対辺7mm・厚さ3.2mmを初期モデルとしています。購入品の寸法と試験片の適合を確認してください。ねじ山、ガードの細部、防振部品は参照モデルに厳密には再現していません。

1. 左右の側板の差込口に3本の支持棒を入れ、6本の固定ピンを上から通します。棒は3本とも同じ形です。
2. 前柱の後側に開いた六角穴からM4ナットを入れます。前側の座面まで押し込み、ねじを締めるまでは後ろから保持します。
3. ファンとワイヤーガードをファン保持部へ取り付けます。取付穴の中心間距離は124.5×124.5mm、穴径は4.5mmです。ファン側の固定具に合わせて穴と厚さを確認します。
4. 保持部の下の突起を側板の穴へ差し込み、前から2本のつまみねじを締めます。ねじの頭は前面に出してあるので、取り外すときも前から操作します。
5. 本体と同程度の重さ・接触条件のダミー荷重で、たわみ、接合の緩み、保持部の振動を確認します。異常があれば実機を載せる前に断面や接合を修正します。

実機を載せる段階では、足が2本の支持棒に掛かること、通気口を塞がないこと、背面の全端子にコネクターを挿せることを確認します。模型は足や端子を再現していません。支持位置が合わない場合は、全体モデルの支持棒の配置と側板の差込口を両方調整します。

## ファンは外部電源と手動ダイヤルで調整する

候補はNoctua NF-A14x25 G2 PWMです。ファン本体140×140mm、厚さは防振パッド込み27mm、取付ピッチ124.5mmの公表寸法を使用しています。[Noctua公式仕様](https://www.noctua.at/en/products/nf-a14x25-g2-pwm/specifications)

コントローラーはユーザー所有の温度センサー付き4線PWM基板型です。140mmファン1個につきコントローラー1個を使用します。140mm×2用の接続構成は次のとおりです。

```text
12V 3A ACアダプター → DC電源二股 → ファンコン2台 → 各140mmファン1個
```

120mm×2用は同じ構成を別に用意します。各センサーで個別に温度制御するため、ファンのPWM出力は分岐しません。ケースは外側の共通ドックへ取り付けます。[配置と必要金具](../../fan-controller/docs/ラックへの取り付け.md)を参照してください。初めはファン本体の風向表示とDGXの実際の吸排気方向を確認し、矛盾しない向きに取り付けてください。

室温と処理負荷をそろえて、ラックに置かない場合、ラック＋追加ファン停止、追加ファン運転を比較します。温度、処理速度、本体ファンの音、ラック側ファンの音、フレームの変形を記録して、配置と回転数を決めます。今回のモデル生成では熱解析や温度測定はしていません。

## 2台・4台へ増設する

| 配置 | 基本ユニット数 | 追加する上下ピン | 追加する横クリップ |
|---|---:|---:|---:|
| 2台縦 | 2 | 4 | 0 |
| 2台横 | 2 | 0 | 2 |
| 4台、2段×2列 | 4 | 8 | 4 |

上下ピンの中央のつばが、段間の4mmの隙間を作ります。横クリップは隣接する側板2枚を上からまたぎます。これらは設置中の位置決め用で、機器を載せた状態で運搬するための固定具ではありません。

2段にする前に、下段フレームが上段のユニットと本体の荷重を受ける状態をダミー荷重で確認します。1台分だけの確認では、2段全体の荷重確認を済ませたことにはなりません。

## 形状を変更して書き出す

寸法は `models/spark-rack/source/spark_rack_parameters.py`、形状は `freecad_spark_rack.py` を変更し、生成マクロで再生成します。生成FCStdだけの編集を正本にしません。出力先のSTLを検査する場合は、次の `<実行ID>` を実際のフォルダ名に置き換えます。

```sh
python3 tools/cad/check_stl.py build/spark-rack/<実行ID>/stl --output build/spark-rack/<実行ID>/stl_validation.json
```

この検査スクリプトは、最小座標が0のバイナリSTLを対象にします。GUIから新しく書き出したSTLでは、形式と原点を合わせてから使ってください。寸法検査やソリッドの確認だけで、実物の強度、ASAの収縮、冷却効果は保証できません。

## 試作で合わなかった箇所を記録する

この作業の会話に、部品名、使ったSTL、フィラメント、スライス設定、合わなかった寸法を伝えてください。接合部の写真や測定値があれば、次の寸法調整に使えます。

用語：保持部（カセット）はファンを取り付けて前から外す部品、固定ピンは支持棒を留める棒、上下ピンはユニット間の位置決め部品、PWMはファンへ回転速度を指示する信号です。

更新日：2026年9月16日。

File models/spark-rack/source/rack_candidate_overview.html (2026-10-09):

枠を小型化・電源4個も内蔵する構想

# 本体も電源も、一つの枠へ。

両スイッチの収容を検討しながら余白を詰め、電源4個・120mmファン2個・制御ケース6個を枠内へ配置します。

案 配置 斜めから前面背面・配線側面上面

28mm角の柱・梁DGX Spark140mmファン導風の参考外形電源4個将来のスイッチ収容範囲

共通枠の外形・脚を除く512 × 520 × 420mm

制御ケースまで含む幅512mm

下段の本体底面高さ72mm

## 表示を調整

本体・140mmファン・制御ケース 電源4個・120mmファン・支持範囲 導風の参考外形 40cmケーブルの仮経路 部品の説明

斜め表示はドラッグで回転。枠の細い線は造形分割の候補です。線をまたぐ外板や別部品の継ぎ手は置きません。

## 組立順の考え方

下側の柱と受けを用意梁の段差を載せる水平面を確保。

低いほぞの梁を先に入れる続いて高いほぞの梁を上から入れる。

上側の柱を後から載せる上から入れる接合を、柱で塞ぐ前に組む。

これは角の接合から展開する順序の候補です。全体の分割位置と、最後の梁まで入る経路はこれから詰めます。

全体は外形の構想図です。端の凹凸を全長部材へ統合した製造形状ではありません。梁の取付穴、スイッチ支持板、止めねじは未確定。外形箱と仮配線の干渉を確認しました。全長部材の凹凸、実端子、組立経路、強度・冷却は未検証です。

## 角は、柱の穴と梁のほぞ

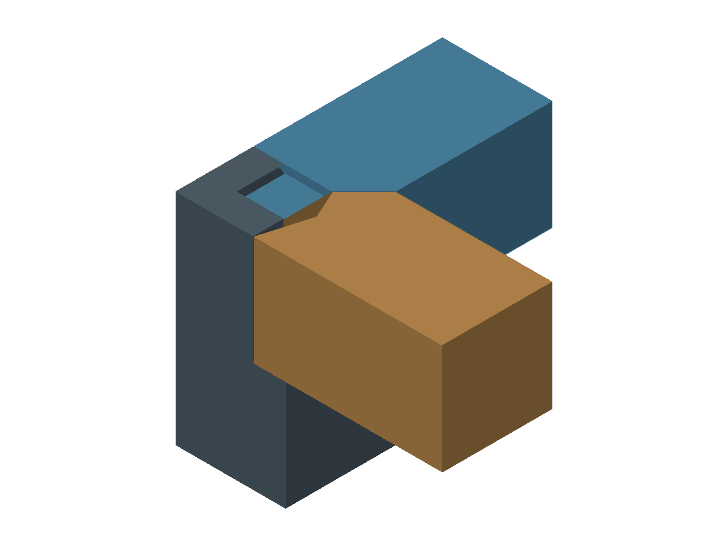
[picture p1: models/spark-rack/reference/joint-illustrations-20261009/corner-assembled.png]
検査済みの短い形状：柱の受けへ梁2本を入れた状態


荷重は根元の段差で受け、奥のほぞで位置を決めます。28mm角の外形に収め、角の固定板をなくします。

## 差す方向を、上からにそろえる

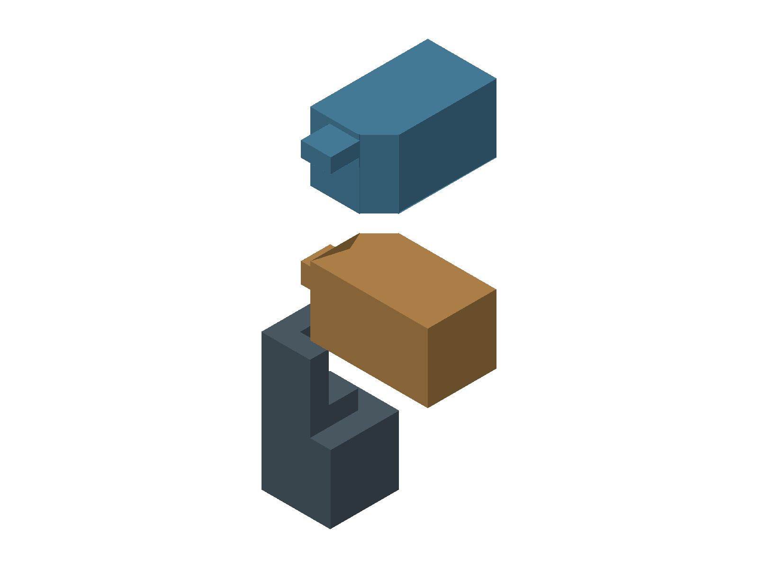
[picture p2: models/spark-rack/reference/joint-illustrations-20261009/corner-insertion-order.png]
低いほぞを先に、高いほぞを後に上から入れる順序


角の短い形状では、低いほぞ→高いほぞの順で挿入できます。全体の順序はこの条件を守って検討します。

## 直線の途中は、二股と差し込み

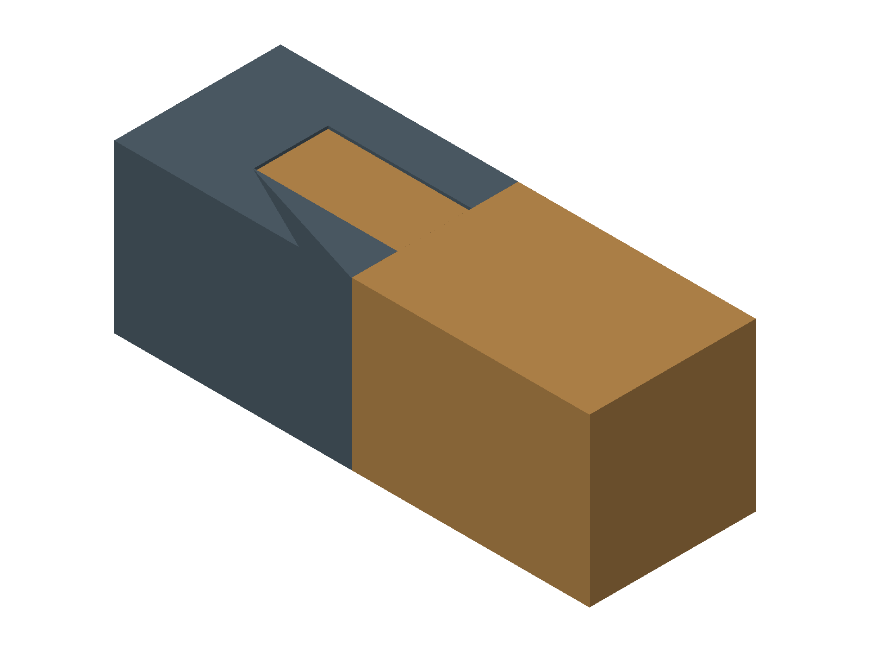
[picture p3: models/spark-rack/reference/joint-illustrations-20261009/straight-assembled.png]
二股の溝へ差し込みを上から入れた短い形状


部材の分割線は残ります。外へかぶせる継ぎ手をなくし、二股の底面で相手を受けます。

本体枠の72個は前の案の数量目標です。電源の支持部、120mmファンの保持部、追加ドック、仕切りを統合した部品数は未確定です。スイッチ支持板は寸法確定後に設計し、試験片の印刷は後回しのままです。

寸法の比較構想図の寸法データ確認範囲生成元と保存記録

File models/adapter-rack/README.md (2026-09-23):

# ACアダプターラック

**正本は `source/` のPython設計コードと寸法定義です。** 生成したFCStdやSTLを編集して正本にはしません。縦横連結・120mmファン対応のv2が現行の設計試作です。

| 変更したいもの | 編集・実行するファイル |
|---|---|
| 寸法と隙間 | [source/adapter_rack_parameters.py](source/adapter_rack_parameters.py) |
| 部品形状と組立配置 | [source/freecad_adapter_rack.py](source/freecad_adapter_rack.py) |
| CAD検査 | [source/validate_adapter_rack.py](source/validate_adapter_rack.py) |
| 出力処理 | [source/build_adapter_rack.py](source/build_adapter_rack.py) |
| 生成を実行 | [source/run_adapter_rack.FCMacro](source/run_adapter_rack.FCMacro) をFreeCADで実行 |
| 購入品の根拠 | [reference/](reference/)の仕様・出典資料 |

出力先はリポジトリ直下の `build/adapter-rack/<実行ID>/` です。実行ごとに新しいフォルダを作り、FCStd・STEP・STL・画像・検査結果・manifestを保存します。正本を選ぶ際に、この出力フォルダからファイルを選ぶ必要はありません。

[設計と組立](docs/設計と組立.md)で構成・部品表・試作手順を確認できます。実物の適合・耐荷重・冷却は未検証です。旧スタンドは[アーカイブ](../../archive/adapter-stand-v1/README.md)に退避しています。

前面保持板は幅164mmのフレームと外形を揃え、高さ144mmとして縦2段（152mm）に対して上下4mmずつ内側へ収めます。ファン上下の余白は12mmです。ファン取付穴・送風開口・ラック固定穴の位置は変更していません。

## ライセンス

[Apache License 2.0](../../LICENSE)

Copyright 2026 IDEO PLUS LLC

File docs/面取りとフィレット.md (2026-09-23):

# 印刷部品の面取りとフィレット

大きな部品の外周はC0.3、小部品はC0.2、ファン送風開口の前縁はR0.3を基準にします。Cは45度の面取り寸法、Rは丸みの半径で、単位はmmです。形状の正本へ加工を反映し、スライサー上の表示だけでは処理しません。

| 部品 | 処理 |
|---|---|
| 本体ラック・アダプターラックの左右側枠 | 外側の広い面にある直線の凸稜線をC0.3。内側の差込面を一括加工しない |
| 両ラックの支持棒・短い棒の試験片 | 側面・上下の外周凸稜線をC0.3 |
| 両ラックのファン保持板 | 前後の外周凸稜線をC0.3、前側の送風開口をR0.3 |
| 横連結クリップ・上下保持板・横連結ブリッジ | 外周凸稜線をC0.3。アダプターラックのブリッジ突起先端はC0.2 |
| 固定ピン・上下位置決めピン | 両端をC0.2。軸径と中央の接触部は保持 |
| 接合試験片 | 対応する側枠と同じ外側の広い面のみC0.3。差込口の加工条件を変えない |
| 金具試験片 | 外周をC0.3。測定対象の円形穴・六角穴の縁は保持 |
| 共通ドック | 外形R4、外周上下の稜線R0.4、通風窓の角R4、ケース側の直線の凸稜線C0.3 |
| ファンコンケース本体 | 既存の外周R3、上下端R0.4、配線開口の外縁R0.3を維持 |
| ケースの取付耳 | 先端R3、上面外周R0.3。M3の90度皿座は保持 |
| 蓋 | 既存の外周R3・天面の縁R0.4を維持 |
| 独立した基板押さえ | 上面の外周凸稜線C0.2。下面の着座面とねじ穴は保持 |

全稜線へ無条件に加工することはしません。既に丸まった面、凹稜線、円形の取付穴・ねじ座・差込面などは除外し、部品ごとに指定した面と外接面の交線から外周を選びます。切抜きの入口も立体としては凸稜線になるため、凸判定だけでは選びません。横連結クリップは外側面と天面に限定し、差込口の入口を保護します。ファン保持部の表裏は突起先端ではなく板本体の面を指定します。共通ドックの通風窓とピン先端など、意図した入口処理は別に指定します。

共通処理は [edge_finishing.py](../tools/cad/edge_finishing.py) です。アダプターラックでは寸法変更に伴う稜線番号の変化を避けるため、加工前フィーチャーと対象面を保持するPythonフィーチャーで再計算します。再計算にはこのモジュールが読み込まれている環境が必要です。通常どおり生成マクロを使ってください。保存済みの形状だけを編集して正本とはしません。

検査では有効な単一ソリッド、組立干渉、差込口の向き、上下接触面、寸法変更・復元、FCStd再読込、STLの閉じた形状を確認します。面取り後は上下の平面面積が変わるため、差込口が上を向くことは空洞内部と背面の検査点で判定します。手触り・実物の適合・強度は試作で確認してください。

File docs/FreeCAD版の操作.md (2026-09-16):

# FreeCADでラックを開く

[DGX-SPARK-RACK-FREECAD-v1.FCStd](../DGX-SPARK-RACK-FREECAD-v1.FCStd)をFreeCADで開いてください。4台の組立、印刷部品12種類、参考用の寸法表を1つのファイルにまとめています。[全体画像](../exports/freecad/four_units.png)も参照できます。

全体モデルはソリッドとして取り込んだ形状です。スケッチ・寸法連動・ジョイントの設計履歴は含みません。モデルはこのFCStdだけで開けます。

## ツリーの使い方

| 項目 | 内容 |
|---|---|
| ラック_4台組立 | 初期表示。左下・右下・左上・右上の4ユニットと連結部品 |
| 印刷部品_12種類_個別表示用 | 左右側板、支持棒、ピン、保持部、試験片などのソリッド。初期状態では非表示 |
| 変換元の寸法_参考用_形状には非連動 | 33個のパラメーターと式を記録した参考表 |

組立は128個のソリッド、全体外寸は434 × 235 × 347.5 mmです。本体、ファン、ガード、ねじ、ナットも含みます。金色がDGX本体、緑がピンとクリップです。色は識別用で、材料特性を設定したものではありません。

個別部品を見るには、「ラック_4台組立」を選択してSpaceキーで非表示にし、「印刷部品」の中から見たい部品を選んでSpaceキーで表示します。戻すときはその部品を非表示にし、組立を表示します。

参考表を編集しても形状は変わりません。全体モデルの形状を編集するときは、対象のソリッドに加工を追加するか、部品を作り直します。比較試験だけに使ったモデルとコードは削除しています。

## 印刷と書き出し

印刷には[部品別STL](../exports/freecad/stl)を使ってください。組立全体には購入部品の参照形状も入っているため、そのまま印刷しません。造形方向や接合部の確認は[試作ガイド](試作ガイド.md)にまとめています。

編集したFCStdを保存し、書き出す部品だけを選択してFreeCADのエクスポートを使います。CAD間で形状を渡す場合はSTEP、スライサーへ渡す場合はSTLを選びます。STLでは単位と造形方向を確認してください。

保存済みの[組立STEP](../exports/freecad/DGX-SPARK-RACK-v1.step)と[部品別STEP](../exports/freecad/parts)は、元の形状を保持する汎用データです。FreeCADモデルを編集しても、これらのファイルやSTLは自動では更新されません。

## 保存している記録

[manifest.json](../exports/freecad/manifest.json)にFCStd・STEP・STLの場所とハッシュを記録しています。[STL検査記録](../exports/freecad/stl_validation.json)には閉じた形状、接続成分、体積、造形寸法を記録しています。実物の強度、放熱、造形の適合は別途確認が必要です。

ファイル内に残る変換元名や識別用の属性は過去の記録です。外部のCADファイルを読み込むリンクではありません。旧CAD専用のファイルやプログラムは、現在の作業に不要なため削除しました。

過去にmacOSの画面情報取得を伴う操作でクラッシュが発生したため、自動操作にはFreeCAD MCPを使っています。FreeCADを手動で使う場合、MCPの起動は不要です。

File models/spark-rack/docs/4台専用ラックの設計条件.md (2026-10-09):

# 4台専用ラックは2列×2段と中央のスイッチ置き場で設計する

DGX Sparkが4台になったため、最初から4台を支える共通フレームへ設計を改めます。配置は2列×2段とし、将来のスイッチはラック内の交換可能な置き場に載せます。当初は両接続とも50cmの指定でしたが、その後に**QSFP112ダイレクトアタッチケーブル40cmを4本所有している**ことが分かりました。手持ち40cmと当初の50cmを比較します。

2026年10月9日のユーザー指定を記録した設計条件です。[調整できる仮配置と参照モデル](仮配置の確認.md)を作成しました。ラック外形や印刷部品の寸法はまだ確定していません。連結式の従来設計は[保全パッケージ](../../../archive/spark-rack-modular-20261009/README.md)に残しました。

## 基本方針を維持し、136部品案を不採用とする

2026年10月9日に、ユーザーから「方針は問題なさそうです」と確認を受けました。4台専用の2列×2段、本体用140mmファン4個、電源用120mmファン2個、将来の交換可能なスイッチ置き場を基本案として採用します。電源は当初別置きでしたが、その後のユーザー指定で枠内への統合を検討する方針へ変わりました。同じ4台用フレーム内で支持段を移動し、リング運用とスイッチ接続に対応する方針です。

構成の方針は維持します。2026年10月9日17:21の136部品案は採用せず、[部材の凹凸と段差を持つ次案](凹凸の接合試験片と次案.md)へ進みます。下段高さと制御ケース位置は共通定義にそろえ、未測定の端子位置から梁へ取付穴を固定しません。スイッチ支持板は耳込み幅と奥行が確定してから設計します。

## 確定した条件

| 項目 | 条件 |
|---|---|
| 本体 | DGX Spark 4台、2列×2段 |
| 枠の構成 | 4台用の共通フレーム。1台用ラックを増設する連結機構は不要 |
| 当面の接続 | 4台を輪につなぐリング接続。手持ち40cm×4本と当初の50cm条件を比較 |
| 将来の接続 | MikroTik CRS812またはCRS804へ接続。当初は50cm。手持ち40cmの再利用は電気的な適合を確認する |
| スイッチの収容 | ラック内に交換可能な設置場所を用意する。機種は未確定 |
| 冷却部品の用途 | 本体用140mmファン4個を用意予定。電源用120mmファン2個は枠内統合案でも電源用へ割り当てる。既存のファンコントローラーケースの設計を利用する |
| 旧設計 | ファイルを保全し、従来版と新設計を区別する |

4台用の共通フレームでも、プリンターの造形範囲に合わせて部品を分割して組み立てられます。不要なのはラックの増設用連結機構であり、造形部品の組立接合まで一体造形に限定する指定ではありません。

## リングは隣接する4台を一周させる

次の図は背面から見た配置です。全台の背面端子を同じ側へ向け、横方向2本と縦方向2本で一周させます。図中の台番号は配線を識別するための仮番号です。

```mermaid
flowchart TB
  subgraph upper[上段]
    direction LR
    a[左上のSpark・1台目] ---|40／50cm| b[右上のSpark・2台目]
  end
  subgraph lower[下段]
    direction LR
    d[左下のSpark・4台目] ---|40／50cm| c[右下のSpark・3台目]
  end
  a ---|40／50cm| d
  b ---|40／50cm| c
```

| ケーブル | 接続先 | 配線する方向 |
|---|---|---|
| 上段の横配線 | 左上と右上 | 横 |
| 右側の縦配線 | 右上と右下 | 縦 |
| 下段の横配線 | 右下と左下 | 横 |
| 左側の縦配線 | 左下と左上 | 縦 |

各台で左右2つの高速接続端子を使います。どちらの端子を隣のどの端子へつなぐかは、実機の位置とケーブルの引き出し方向を測ってから決めます。輪の閉じ方に対角配線を使わず、最長経路を抑える方針です。

ここで記録するのは物理配線の条件です。4台リングでのネットワーク設定と分散処理の動作は、ラックの形状検査とは別に確認します。

## スイッチの端子を上下段の間へ近づける

スイッチは上下段の間に置き、スイッチの接続端子面をSparkの背面端子に近い面へそろえる案を第一候補とします。上段・下段の両方から短いケーブルで届く位置を探します。置き場は交換できる支持板とし、機種による幅・奥行・端子位置の違いを調整できるようにします。

```text
背面側の配置案（寸法未確定）

  [左上のSpark]       [右上のSpark]
          ＼           ／
       [スイッチの接続端子面]
          ／           ＼
  [左下のSpark]       [右下のSpark]

各Sparkからスイッチまで40cmと50cmの条件を比較する。
リング運用時もSparkの配置は同じ。
```

スイッチ接続時は各Sparkからの4経路を個別に検査します。端子が機器の中央にあるとは仮定しません。リング用の4本をそのまま流用できるかは、コネクターの規格と選ぶスイッチの対応を確認してから判断します。

スイッチの端子面、Sparkの背面、電源の端子は抜き差しできるように開放します。スイッチの前後方向は実機の吸排気と電源の交換方向を確認して決め、短い配線のために通風や保守を塞がない配置を選びます。

## 寸法の根拠と未確定値

| 対象 | 公開資料の値 | 設計への扱い |
|---|---|---|
| DGX Spark | 幅150×奥行150×高さ50.5mm、質量1.2kg | 本体4台で4.8kg。足の接触位置と端子位置は実測が必要 |
| CRS812-8DS-2DQ-2DDQ-RM | 製品資料は443×268×44mm。公式取扱説明は443×156×44mm | 奥行の記載が不一致。仮配置では大きい268mmを使い、最終寸法は確認する |
| CRS804-4DDQ-hRM | 公式寸法図に218、360、387、44mmの寸法がある | 筐体と突出部の区別を寸法図で確認してから収容形状へ反映する |
| ケーブル | 所有40cm×4本、当初指定の50cmも比較 | 長さの測定基準、コネクター長、曲げ半径、引き出し余裕は型番または実測で確認する |

出典は[NVIDIAの本体仕様](https://docs.nvidia.com/dgx/dgx-spark/hardware.html)、[CRS812製品資料](https://cdn.mikrotik.com/web-assets/product_files/CRS812-8DS-2DQ-2DDQ-RM_251055.pdf)、[CRS812公式取扱説明](https://help.mikrotik.com/docs/spaces/UM/pages/340492410/CRS812-8DS-2DQ-2DDQ-RM)、[CRS804公式寸法図](https://cdn.mikrotik.com/web-assets/product_files/CRS804_dimensionsR0_260152.pdf)です。確認日は2026年10月9日です。

旧ラックの幅210×奥行230×高さ170mm、140mm追加ファン、外置き電源アダプターは従来設計の値です。新ラックに採用する値は、配線と通風を含む配置を比較して決めます。本体と電源のファンの用途は下記の構成で採用します。電源アダプターの実物適合と使用材料は未確定です。

## 手持ちのファンを使う取付場所を設ける

ユーザー指定は、140mmをDGX Spark用に合計4個用意し、120mmは電源アダプター用へ使う構成です。120mmの個数は既存図面にある2個を基準とします。140mmの4個は用意予定であり、全数を所有済みと確認した記録ではありません。

本体側はSpark各台へ140mmを1個ずつ割り当て、前面側に取り外せる保持部を置きます。電源側は共通枠の手前下側へ4個を2列×2段で置き、左右の120mmファン各1個から側面へ排気する構想です。電源と本体の間に参考の仕切りを置きます。既存の別置きラックも保持します。120mmをSparkへ振り替えません。吸排気方向と冷却効果は実機で確認します。

ファンを個別制御する既存方針では、本体側4組と電源側2組、合計6組のコントローラーとケースが必要です。既存ケースの設計を使い続け、必要数と所有数は区別します。

ファンを含む配置は、スイッチ、支持部、ファンコントローラーケース、ガード、配線との干渉を検査してから採用します。配置参考には140mmファン4個と制御ケース4個の参考外形を残します。保持部へ導風を加える次案は形状検討に留め、未測定の通気口へ固定しません。スイッチ接続時は上下中心間隔220mm、当面のリング運用はスイッチを外して160mmとし、同じ4台用フレーム内で支持段を移動する案です。Sparkの支持範囲は本体の奥行150mmに合わせました。取付金具、実際のケース形状と配線の操作空間、冷却効果は未検証です。

## 40cmと50cmに収まるかはケーブルの経路で判定する

端子間の直線距離が公称長より短いだけでは、ケーブルが届くことの確認にはなりません。端子から真っすぐ引き出す部分、曲げる部分、ケーブルを支える経路を含めて判定します。両端コネクターの長さをケーブルの公称長へ含むかも確認します。

寸法を決める前に、実機とケーブルの型番・端子位置・曲げ条件を記録します。その値でリング4経路とスイッチ4経路の配置模型を作り、各経路の長さ、余り、抜き差し空間を検査します。曲げ条件が不明な経路は未検証のまま扱います。

配線が収まる配置を選んでから、共通フレーム、支持部、スイッチ支持板、配線保持部を設計します。部品分割は造形範囲に合わせて決めます。本体4台に加えてスイッチ・支持板・必要な冷却部品の荷重を確認し、実物の適合・耐荷重・冷却を試作で検証します。

配置模型では、仮の端子位置と曲げ条件で配線を評価しています。[136部品案](4台ラックの部品案.md)は不採用です。部品案の下段は72mmへ上げ、接続金具と下側の外周梁の重なりを避けています。採用前に実測値を反映し、接続部分から試作します。

## 手持ち40cmのスイッチでの動作は未確認

ELSAの[40cm製品TS000111](https://www.elsa-jp.co.jp/products/detail/nvidia-dgx-spark-cable/)はSpark同士の接続用として掲載されています。手元の製品がこの型番かは未確認です。MikroTikの[対応仕様](https://help.mikrotik.com/docs/spaces/ROS/pages/220233794/MikroTik%20wired%20interface%20compatibility)はCRS812のQSFP56端子と両機種のQSFP56-DD端子で、銅線4レーンの200ギガビット毎秒接続に対応すると記載しています。手元の40cmケーブルの認識と安定動作は未確認です。

一方、ELSAの[50cm製品IN000200](https://www.elsa-jp.co.jp/products/detail/qsfp56-200g-dac-cable-50cm_h/)にはMikroTik 804/812との接続確認が明記されています。40cmの製品へその確認結果を引き継ぎません。実機の識別表示を確認してから再利用の可否を判断します。

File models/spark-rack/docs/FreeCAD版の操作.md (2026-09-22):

# FreeCADでの生成と確認

1. [run_spark_rack.FCMacro](../source/run_spark_rack.FCMacro) をFreeCADで実行します。
2. `build/spark-rack/<実行ID>/` の `manifest.json` と検査結果が成功していることを確認します。
3. 同じフォルダの `DGX-SPARK-RACK.FCStd` と配置画像で形状を確認します。
4. 印刷には同じ実行の `stl/` 内の個別部品を使います。購入部品の参照形状を含む組立全体は印刷しません。

寸法変更は [spark_rack_parameters.py](../source/spark_rack_parameters.py)、形状変更は [freecad_spark_rack.py](../source/freecad_spark_rack.py) に反映して再生成します。生成FCStdの寸法表は記録用で、形状と連動しません。

STLの閉じた形状などのCAD検査と、実物の適合・強度・冷却は別です。[試作ガイド](試作ガイド.md) も参照してください。

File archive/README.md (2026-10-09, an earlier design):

# アーカイブ

このフォルダは現行設計から外したものの保管先です。現在編集する正本は [../models/](../models/) にあります。

| 場所 | 保管するもの |
|---|---|
| [spark-rack-overview-20261009-200723](spark-rack-overview-20261009-200723/README.md) | 電源を内蔵する前の全体構想。現行画面での比較用データ |
| [spark-rack-structure-rejected-20261009-172152](spark-rack-structure-rejected-20261009-172152/README.md) | 不採用の136部品案。指定実行の生成物とレビュー受領時の作業コードを区別して保全 |
| [spark-rack-modular-20261009](spark-rack-modular-20261009/README.md) | 4台専用ラックへの再設計前のリポジトリ一式。日付付き保存パッケージと内容照合の記録 |
| [adapter-stand-v1](adapter-stand-v1/README.md) | 横連結のみの旧スタンド。コード・資料・生成物を一式で保全 |
| [print-projects](print-projects/README.md) | 採用しなくなった印刷配置とバックアップ |
| [fan-controller-import](fan-controller-import/README.md) | 別worktreeから取り込んだケースの原マクロ・画像・検査記録 |
| [spark-rack-fcstd-v1](spark-rack-fcstd-v1/README.md) | Python移行前の本体ラックのFCStdと生成物 |
| `build-history/` | 整理前のローカル再生成結果。Git管理対象外 |
| [layout-history](layout-history/) | 整理前の説明。パスは当時の記録で、現在の操作には使わない |

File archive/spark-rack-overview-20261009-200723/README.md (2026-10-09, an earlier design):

# 小型化前の全体構想を比較用に保全

枠520×530×420mm、制御ケースを含む幅618mm、電源は別置きの構想図です。小型化して電源を内蔵する案と画面で比較するため、元の寸法データと検査結果を内容を変えずに保全しました。

現行部材の形状へ採用する入力ではありません。`build_rack_candidate_overview.py`は、このデータを比較表示として明示的に読み込みます。現在の寸法と機器配置はPythonから別に生成します。

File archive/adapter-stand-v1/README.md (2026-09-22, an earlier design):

# 旧アダプタースタンドv1

横連結だけに対応した旧モデルです。現行は [アダプターラック](../../models/adapter-rack/README.md) を参照してください。

- `source/`：当時のPython設計コードと寸法定義。配置変更に伴う参照パスのみ更新。
- `reference/`：旧版が参照する電源仕様のスナップショット。
- `generated/`：保存済みFCStd・STL・画像・検査記録。
- [docs/設計と組立.md](docs/設計と組立.md)：旧版の説明。

旧版を再生成する場合だけ `source/run_adapter_stand.FCMacro` を使います。出力は `archive/build-history/adapter-stand/<実行ID>/` に作成し、保存済み生成物は上書きしません。

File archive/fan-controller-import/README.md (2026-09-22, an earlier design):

# ファンコンケースの取り込み前データ

別worktreeの `designs/fan-controller/` を内容変更なしで保全したものです。ファイルの由来とSHA-256は [import-manifest.json](import-manifest.json) にあります。

現行の編集先は [models/fan-controller](../../models/fan-controller/README.md) です。このフォルダのマクロ・画像・検査記録は取り込み時の履歴として扱います。既存画像が最新寸法を反映するかは未確認です。

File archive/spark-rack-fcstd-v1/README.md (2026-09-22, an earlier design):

# 本体ラックのPython移行前データ

旧FCStdを `source/`、既存STEP・STL・画像・検査記録を `generated/` に保全しています。現行の正本は [models/spark-rack](../../models/spark-rack/README.md) のPythonです。ここは移行前の形状との比較用で、現行の生成処理は参照しません。

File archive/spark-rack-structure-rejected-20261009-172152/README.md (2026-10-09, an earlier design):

# 17:21の136部品案は不採用として保全する

この案は不採用です。

ユーザーレビューの対象は`build/spark-rack/four-node-structure/20261009-172152-7b36234b`です。136部品、288本の締結経路を持つ案は採用せず、[保存パッケージ](four-node-structure-20261009-172152-not-adopted.zip)へ保全しました。指定実行の文書・立体データ・画像・検査結果・元manifestは変更していません。

`generated/`は指定実行の生成物、`working-source-at-rejection/`はレビューを受領した時点の作業コードです。当時の入力コードを生成時に複製していなかったため、後者が元manifestの入力と一致するとは限りません。一致した入力と、ここに保存できていない当時の入力版は[preservation-manifest.json](preservation-manifest.json)に区別して記録しました。

旧案のM4×45などの金具一覧、横梁を45度に置く印刷向きは、この履歴に保持します。136部品案を印刷せず、次は部材の凹凸と段差を持つ短い試験片で検討します。

## 履歴確認用の実装

不採用の実装は`source/`へ移しました。元の保存パッケージと内容照合記録は変更していません。再生成する場合は、リポジトリのルートから次を実行します。

```sh
python3 archive/spark-rack-structure-rejected-20261009-172152/source/build_four_node_structure.py --historical
```

出力は`archive/build-history/four-node-structure-not-adopted/<実行ID>/`です。この実装が利用する現在の配置・共通基準・ドックのコードも、同じ実行の生成記録へ含めます。保存パッケージをそのまま復元することと、現在の共通処理で履歴形状を再生成することは区別してください。

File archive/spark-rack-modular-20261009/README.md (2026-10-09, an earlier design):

# 連結式ラックの設計を2026年10月9日時点で保全

4台専用ラックへの再設計前のデータを、[dgx-spark-modular-rack-repository-20261009.zip](dgx-spark-modular-rack-repository-20261009.zip)に保存しました。本体ラック、電源アダプターラック、ファンコントローラーケースの設計コード、説明、印刷設定、共通ツール、過去のアーカイブを含みます。展開すると当時のリポジトリ構成に戻ります。

保存時のファイル一覧、内容を照合するSHA-256ハッシュ、元のコミットは[preservation-manifest.json](preservation-manifest.json)、圧縮ファイルの検査と全ファイルの一致確認は[preservation-validation.json](preservation-validation.json)に記録しました。人間専用の`AGENTS.md`は複製対象から外しています。このworktreeには`build/`の生成履歴がありません。別worktreeやFreeCADの未保存文書は、この保全には含みません。

## 旧版と新設計を区別する

保存パッケージの名前は「対象・連結式・保全日」でそろえました。作業側の本体ラック用印刷設定にも`modular-spark-rack-`を付け、4台専用の新設計用と区別しています。名前の対応はmanifestの`renamed_working_files`にあります。圧縮ファイル内には変更前の名前と内容を保持しています。

Pythonと実行マクロの名前は、読み込み関係を保つため変更していません。作業側の`models/`と生成タスクにも従来の実装を残しています。現在の本体ラック生成タスクは連結式ラックを作ります。新しい4台専用ラックには[仮配置の検討モデル](../../models/spark-rack/docs/仮配置の確認.md)を用意し、印刷部品はまだ実装していません。

## 取り出すときは別フォルダへ展開する

圧縮ファイルは空の作業フォルダへ展開してください。現在の`models/`へ展開すると新設計を上書きするおそれがあります。当時の説明や検査記録は、保存時のパスを記録したものです。

旧版を再生成する場合は、出力をリポジトリの`archive/build-history/`内の新しい実行フォルダへ指定します。保存済みの設計ファイルや印刷設定に上書きしません。再生成にはFreeCADなど、当時の生成手順に記載した環境が必要です。

次の設計条件は[4台専用ラックの設計条件](../../models/spark-rack/docs/4台専用ラックの設計条件.md)に記録しています。

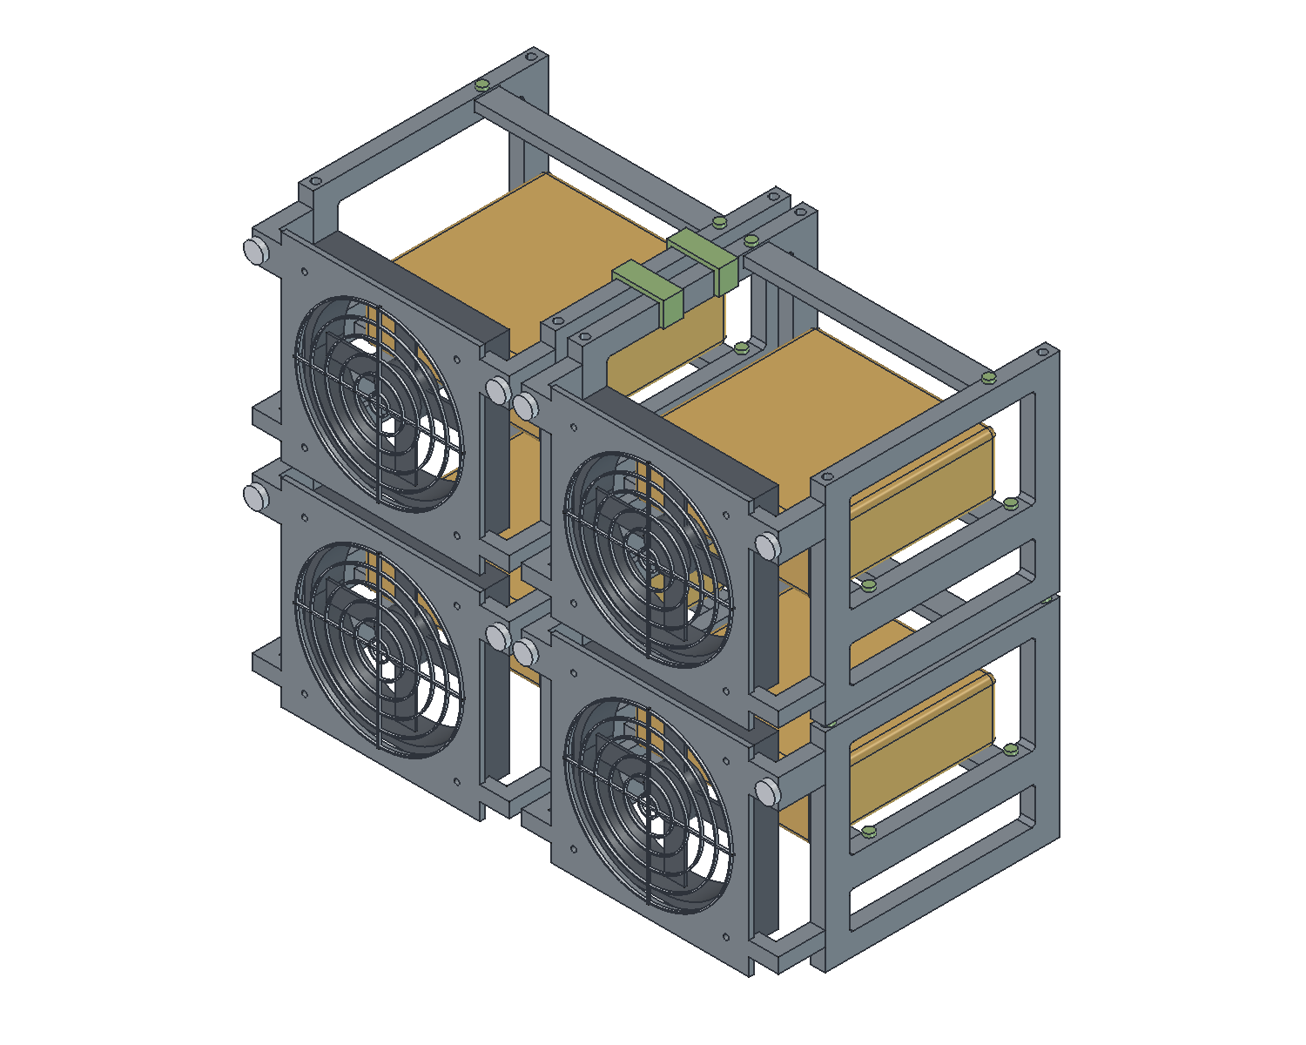
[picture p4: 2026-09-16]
exports/freecad/four_units.png

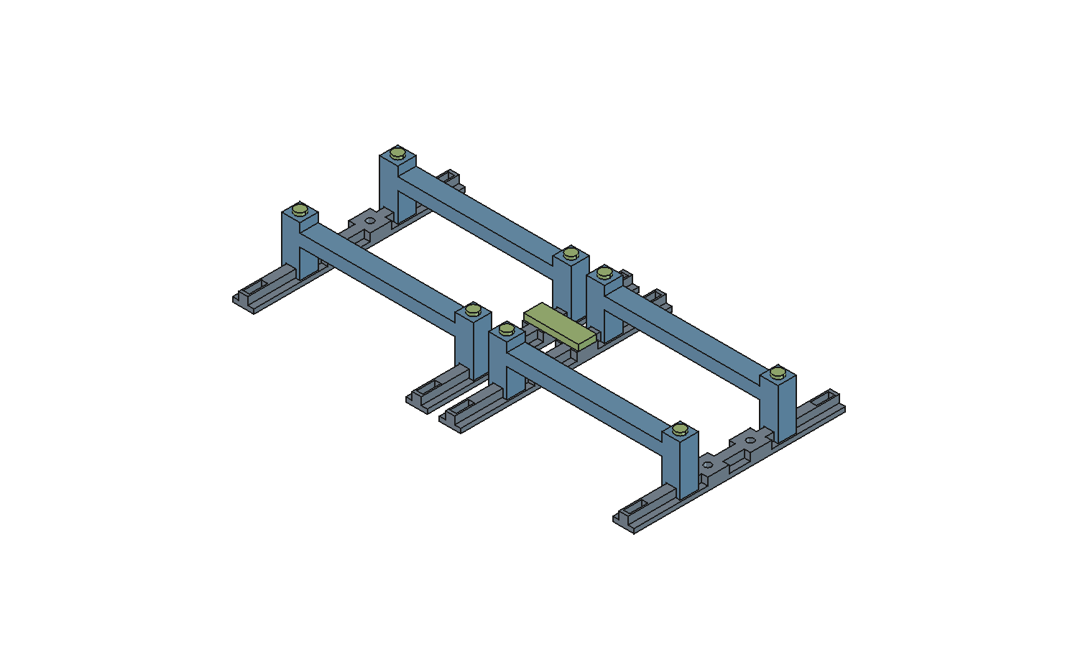
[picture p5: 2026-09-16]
exports/adapter-stand/stand_only.png

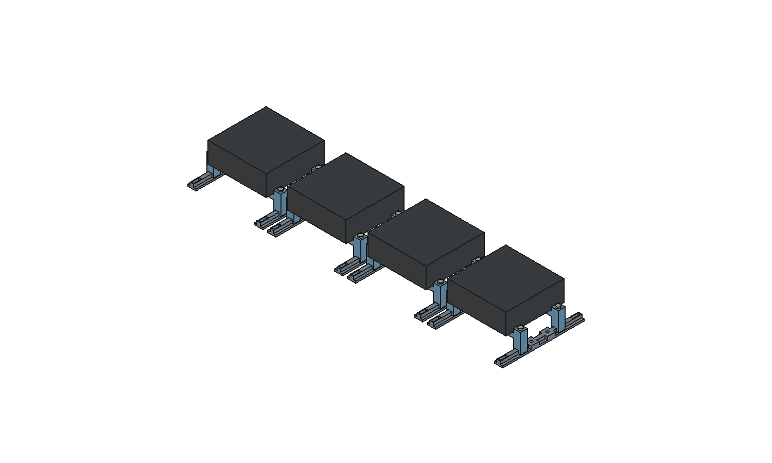
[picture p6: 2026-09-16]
exports/adapter-stand/four_units.png

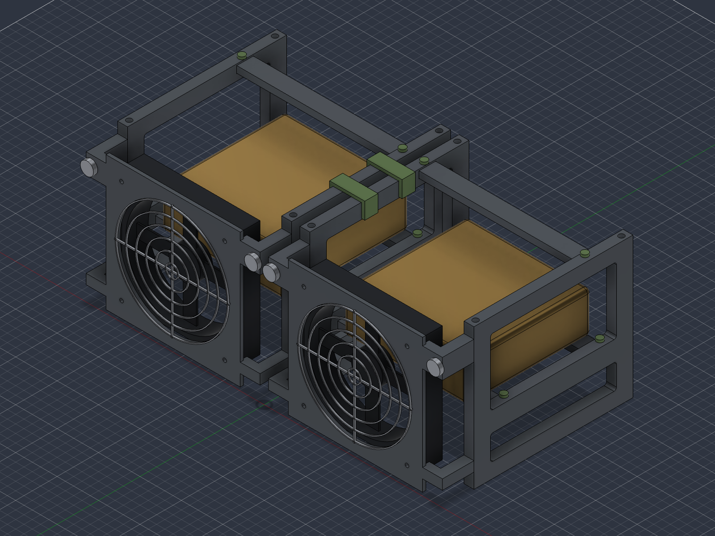
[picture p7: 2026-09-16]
exports/freecad/two_horizontal.png

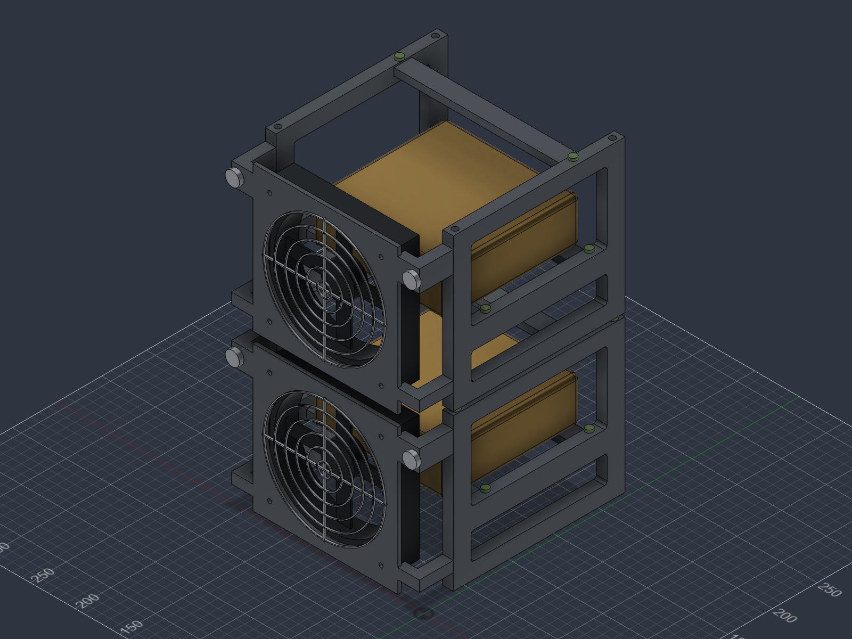
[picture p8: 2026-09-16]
exports/freecad/two_vertical.png

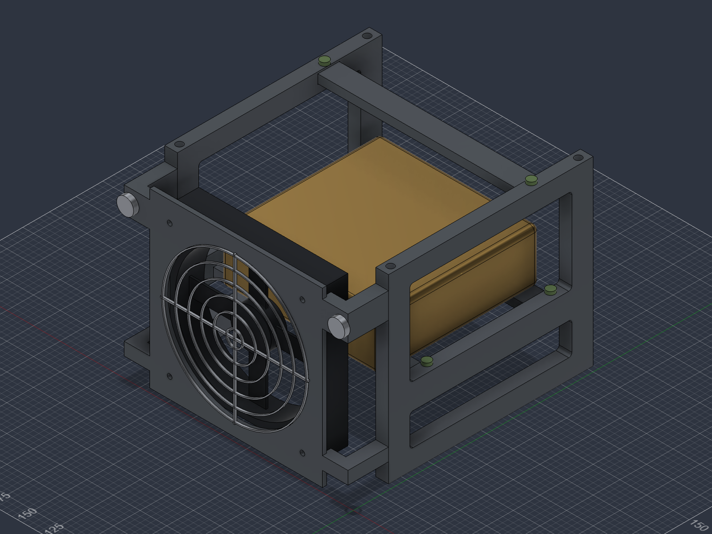
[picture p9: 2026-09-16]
exports/freecad/single.png

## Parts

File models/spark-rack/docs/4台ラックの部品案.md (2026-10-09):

# 共通枠・通気トレー・140mm保持部を部品として確認する

**この136部品案は不採用です。印刷しません。** 対象は2026年10月9日17:21の生成で、[生成物を保全](../../../archive/spark-rack-structure-rejected-20261009-172152/README.md)しています。現在の入口と条件は[凹凸の接合試験片と次案](凹凸の接合試験片と次案.md)を参照してください。以下は旧案の構造・金具・印刷向きを残す履歴です。`structure:spark-rack`は接合試験片のみの生成へ変更しました。

4台専用ラックの構成を、ボルト穴と接続金具を持つ部品案へ具体化しました。28mm角の柱と梁で共通枠を作り、Spark各台を通気トレーで支え、140mmファンは取り外せる保持部へ固定します。リング用とスイッチ用では同じ部品を使い、上段の支持位置を60mm移動します。

これは全体を樹脂部品で作る第一案です。部品数は136個と多く、実物の強度・適合は未検証です。まず接続金具と短い角材を試作し、全体の部品数や金具を減らす余地も評価します。初回は生成方法と構造の説明を読み、部品表と金具は必要なときに参照してください。

## 生成して組立図と個別部品を開く

FreeCADの実行環境で、リポジトリのルートから実行します。

```sh
mise trust
python3 archive/spark-rack-structure-rejected-20261009-172152/source/build_four_node_structure.py --historical
```

出力は `archive/build-history/four-node-structure-not-adopted/<実行ID>/`。実行ごとに新しいフォルダへ保存します。`four-node-structure.html`で配置方式と機器表示を切り替えられます。`four-node-structure-ring.FCStd`で当面のリング用、`four-node-structure-crs812.FCStd`または`crs804.FCStd`で将来の配置をFreeCADで確認できます。

各部品の立体データは`stl/`、交換用の立体データは`parts/`、組立図は各方式の画像にあります。部品数と金具は`structure-report.json`、形状・干渉・締結経路は`validation.json`、保存後の再読込は`assembly-validation.json`、生成元と出力の内容照合は`manifest.json`を参照してください。

FreeCADの実行入口は[run_four_node_structure.FCMacro](../../../archive/spark-rack-structure-rejected-20261009-172152/source/run_four_node_structure.FCMacro)です。部品案の寸法は[four_node_structure_parameters.py](../../../archive/spark-rack-structure-rejected-20261009-172152/source/four_node_structure_parameters.py)、形状は[freecad_four_node_structure.py](../../../archive/spark-rack-structure-rejected-20261009-172152/source/freecad_four_node_structure.py)、生成は[build_four_node_structure.py](../../../archive/spark-rack-structure-rejected-20261009-172152/source/build_four_node_structure.py)で管理します。

従来の本体ラックの正本は保持しています。今回の部品案は採用前の別入口で生成し、通常の`build:spark-rack`と3MF生成タスクは従来モデル用です。本番素材・条件を決める前に、本番用の印刷設定として扱いません。

## 重さはトレー・梁・柱・脚へ伝える想定

共通枠の部材外形は幅520×奥行530×高さ420mmです。制御ケース、脚、接続金具を含む占有範囲は幅618×奥行542.6×高さ428mmです。旧仮配置より幅が増えるのは、制御ケースを側梁の外へ置いて、梁との重なりを解消したためです。

四隅の柱は105mm・222mm・93mmの3部材で構成します。横梁は250mmと214mm、奥行梁は190mm・142mm・142mmへ分割します。これは造形のための部品分割で、1台用ラックを増設する連結構造ではありません。接続部分は56mm長の金具とボルトで固定します。

柱と梁の継ぎ目は、本体支持段や将来の中央支持段と重ならない位置へ置きました。枠の下には着座式の脚を4個置き、接続金具の下面が設置面へ先に当たる状態を避けます。脚は接着・締結を実証したものではなく、枠を載せて位置を確認する試作部品です。

## 本体の支持段は2つの位置を共用する

下段の本体底は設計座標の高さ72mmです。上段はリング用232mm、スイッチ用292mmで、中心間隔は160mmまたは220mmです。脚の下面は設計座標の−8mmなので、設置面からの実高さはそれぞれ8mm高くなります。

各段は側梁2本と横梁2本で構成します。横梁の位置は、本体前端から12mm内側と後端から12mm内側です。トレーは横梁へ載せ、中央の2本の皿ねじで横ずれを留めます。ねじだけで本体荷重を吊るす構造ではありません。

トレーの外形は158×156mm、支持板厚8mmです。4つの通気開口を設け、外周と中央の十字を支持面として残しています。左右と前面には高さ3mmの位置止めを置き、本体外形に対して約2mmの横余裕を仮定しています。足の接触位置と底面通気口は実測後に支持面へ反映します。

上段を移す場合は機器と配線を外し、支持段の側梁・横梁・トレー・ファン保持部・制御ケース取付部を上の位置へ移します。新しいラックを積み重ねる方式ではありません。中央のスイッチ支持板は、柱の取付穴位置の予約までで、支持板とその耐荷重は今回の部品案に含めていません。

## ファン保持部は2本の腕で支持梁へ固定する

本体用は140mmを4個、取付穴の中心間隔124.5mmを基準とします。保持板は幅176×高さ152×厚さ4mm、送風開口は直径132mmです。ファン外形より外側の2本の腕を、支持梁の前面へ固定します。ファンの後端とSparkの前面の間隔は25mmです。

腕には締結部へ工具を入れるための開口を設けました。保持部の固定は左右の2本のねじ、ファンとガードは別の4か所で留めます。保持部を前方へ取り外す想定で、実物のガード・つまみ・工具で操作できるかを試作します。120mmの2個は別置きの電源アダプター用として維持します。

制御ケースには既存の共通ドックを使います。新しい取付板に、共通定義どおり28mm間隔の穴とM4ナットの座を設けました。台座の3mmの突出を含めて接触面を合わせ、支持梁の締結穴とねじ先端の逃げ穴も検査しています。ケース本体は収容範囲の参照形状で、開口ごとの操作空間はまだ確認していません。

## 部品表はリング・スイッチとも同じ

| 部品 | 数量 |
|---|---:|
| 柱の3種類 | 各4、計12 |
| 横梁の2種類 | 各8、計16 |
| 奥行梁の3種類 | 各8、計24 |
| 柱・梁の接続金具 | 32 |
| 側梁と柱の固定板 | 16 |
| 外周横梁と柱の固定板 | 8 |
| 支持横梁の受け、左・右 | 各4、計8 |
| 本体トレー | 4 |
| 140mmファン保持部 | 4 |
| 制御ケース取付板・共通ドック | 各4、計8 |
| 着座パッド | 4 |
| **組立部品合計** | **136** |

印刷形状は試験用の短い角材を含め19種類です。横梁は造形面で45度へ向けて出力します。250mmの部材の造形外形は約196.6×196.6mmとなり、全種類の最大外形は222mmです。外形の検査はスライサーでのサポート、ブリム、禁止領域、収縮まで検証したものではありません。

## 金具は長さの役割を分けて試作する

| 金具の初期案 | 数量 | 主な用途 |
|---|---:|---|
| M4×45六角穴付きボルト | 208 | 接続金具、支持梁受け、制御ケース取付板など |
| M4×40六角穴付きボルト | 16 | 外周横梁の固定板 |
| M4×35六角穴付きボルト | 24 | 四隅の柱へ固定板を留める部分 |
| M4×55六角穴付きボルト | 8 | ファン保持部の腕 |
| M4×45、90度皿ねじ | 8 | 本体トレー |
| M4×45、ファン・ガード用 | 16 | 140mmファン4個 |
| M4×25六角穴付きボルト | 8 | 共通ドック |
| M3×12、90度皿ねじ | 8 | 制御ケースの取付耳 |

M4の必要数は計288本です。M4ナットは各締結に合わせて用意し、柱の四隅と制御ケース取付板では印刷したナット座へ先に入れます。平座金は頭部とナットの座面に合わせて選びます。この一覧は設計上の長さで、購入済み金具の流用や締付けを実証した記録ではありません。トレーの皿頭は外径8.5mm以下、ナット座はM4対辺7mmに対して対辺7.3mmを初期値とします。

## 接続部分を先に試す

`joint_fit_stub.stl`を2個、`splice.stl`を1個印刷し、M4×45とナット4組で接続します。片側隙間0.3mmの差し込み、ねじ穴、締付け時の割れや緩みを確認します。続いてトレー1個とファン保持部1個を作り、本体の足・ファン・ガード・金具・工具の実物に合わせます。

今回の検査は、閉じた単一部品、立体データの閉じた形状、造形外形、3配置の部品間干渉、参照機器との干渉、288本の締結軸、保存後の再読込です。実際の金具の全外形、ねじ同士の干渉、ナットの入れ方、材料の強度、長期荷重、振動、冷却は別に検証します。困った箇所は部品名、生成実行ID、素材、金具寸法とともにこの設計の会話へ記録してください。

用語：共通枠は4台全体を支える柱と梁、支持段は機器を載せる梁とトレー、保持部はファンを固定する前面部品、接続金具は造形のために分割した部材を固定する部品です。

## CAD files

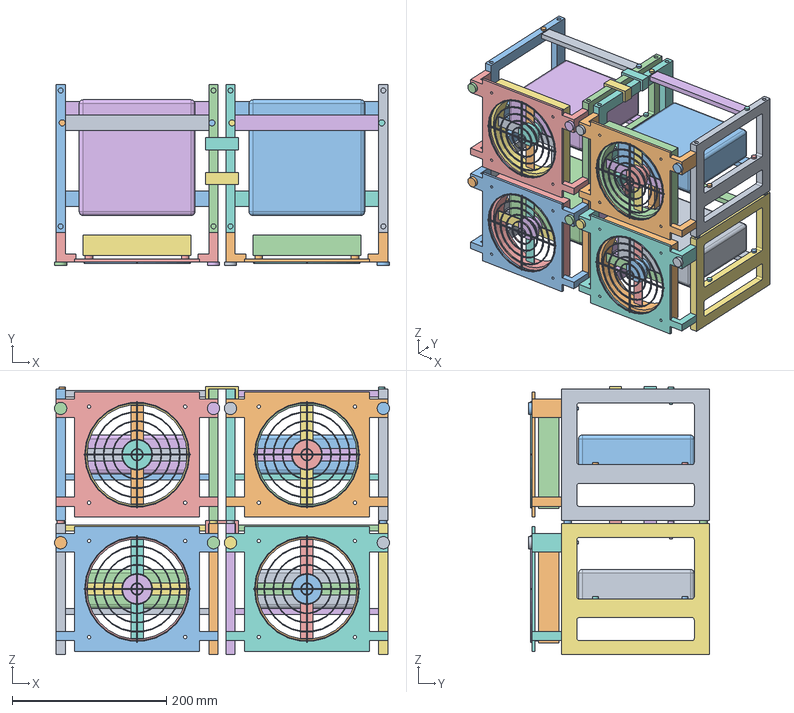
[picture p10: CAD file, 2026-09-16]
DGX-SPARK-RACK-FREECAD-v1.FCStd
434.0 x 235.0 x 347.5 mm
side_L
side_R
fan_cassette
REF_DGX
REF_FAN
REF_FAN001
REF_FAN002
REF_FAN003
REF_GUARD
REF_GUARD001
REF_GUARD002
REF_GUARD003
REF_GUARD004
REF_GUARD005
REF_GUARD006
REF_GUARD007
crossbar
locking_pin
locking_pin001
crossbar001
locking_pin002
locking_pin003
crossbar002
locking_pin004
locking_pin005
REF_SCREW
REF_NUT
REF_SCREW001
REF_NUT001
side_L001
side_R001
fan_cassette001
REF_DGX001
REF_FAN005
REF_FAN006
REF_FAN007
REF_FAN008
REF_GUARD009
REF_GUARD010
REF_GUARD011
REF_GUARD012
REF_GUARD013
REF_GUARD014
REF_GUARD015
REF_GUARD016
crossbar003
locking_pin006
locking_pin007
crossbar004
locking_pin008
locking_pin009
crossbar005
locking_pin010
locking_pin011
REF_SCREW002
REF_NUT002
REF_SCREW003
REF_NUT003
side_L002
side_R002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

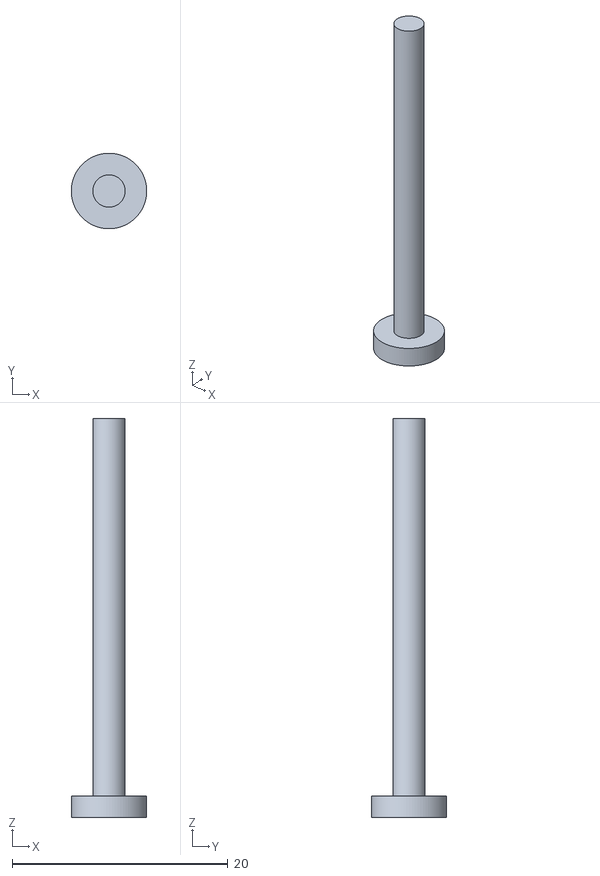
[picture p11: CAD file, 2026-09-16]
exports/adapter-stand/stl/locking_pin.stl
7.00 x 7.00 x 37.0

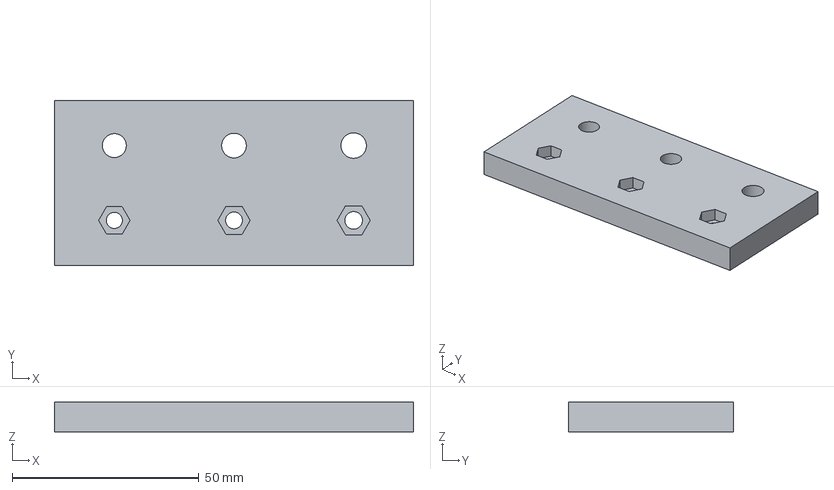
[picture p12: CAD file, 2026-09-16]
exports/freecad/parts/hardware_coupon.step
96.0 x 44.0 x 8.00 mm

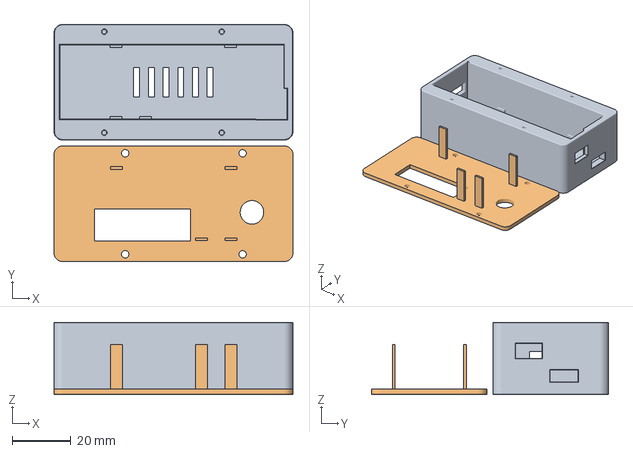
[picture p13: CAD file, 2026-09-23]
print-projects/fan-controller/prototype/fan-controller-blue-pla-body-lid-20260923.3mf
81.4 x 80.8 x 24.7 mm
CaseBody.stl
CaseLid.stl

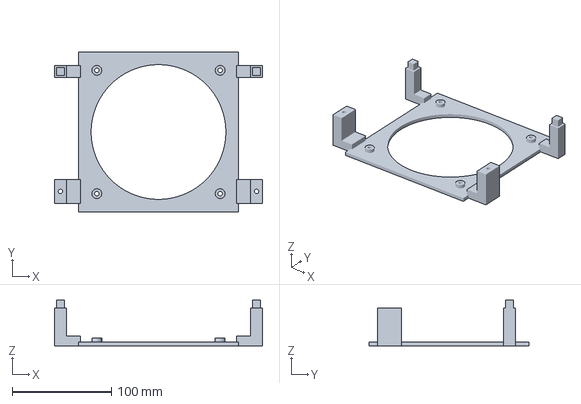
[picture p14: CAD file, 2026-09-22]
print-projects/spark-rack/prototype/modular-spark-rack-pla-fan-cassette.3mf
210.0 x 162.0 x 46.0 mm

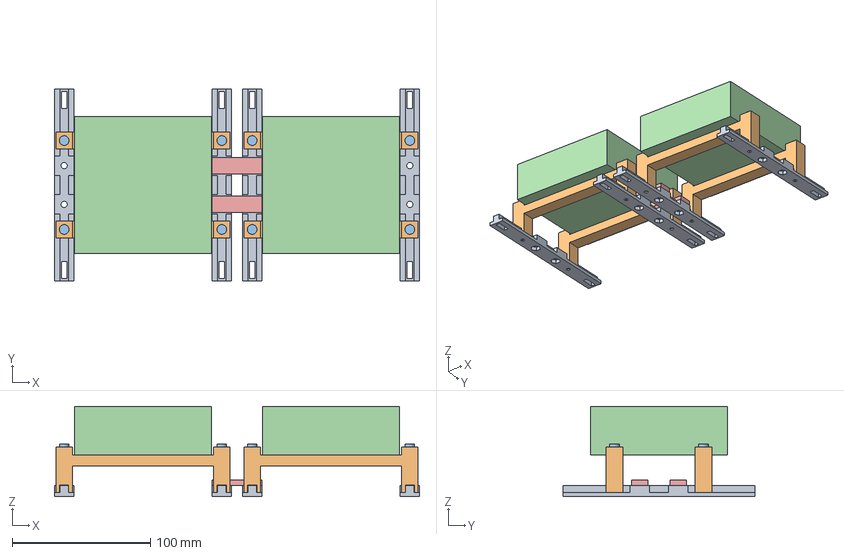
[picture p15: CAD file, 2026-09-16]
DGX-SPARK-ADAPTER-STAND-v1.FCStd
264.1 x 139.0 x 65.2 mm
底レール_左右共通_ファン用M4穴付き x 4
支持台_前後共通 x 4
印刷する固定ピン x 8
参考_ADP-240LB B_公開実測外形 x 2
横連結クリップ x 2

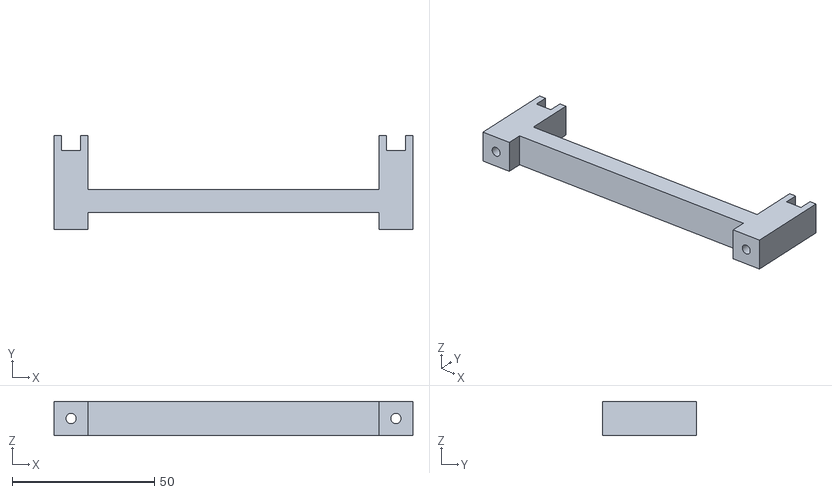
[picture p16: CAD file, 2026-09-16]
exports/adapter-stand/stl/saddle.stl
126.1 x 33.0 x 12.0

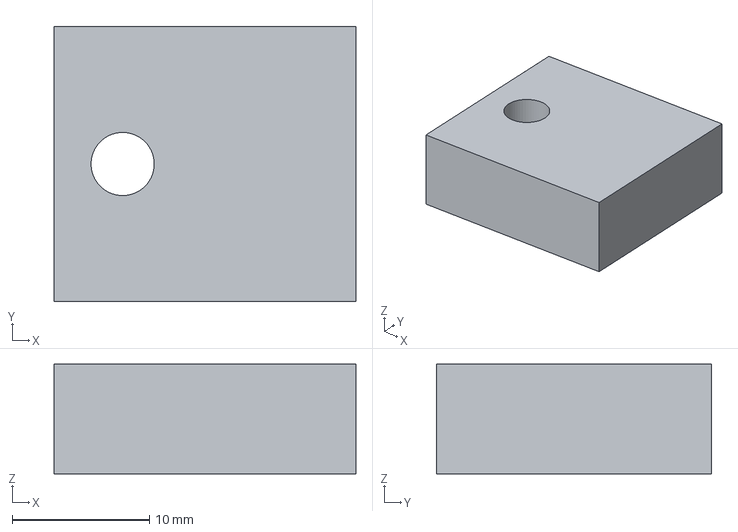
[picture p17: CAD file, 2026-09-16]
exports/freecad/parts/bar_coupon.step
22.0 x 20.0 x 8.00 mm

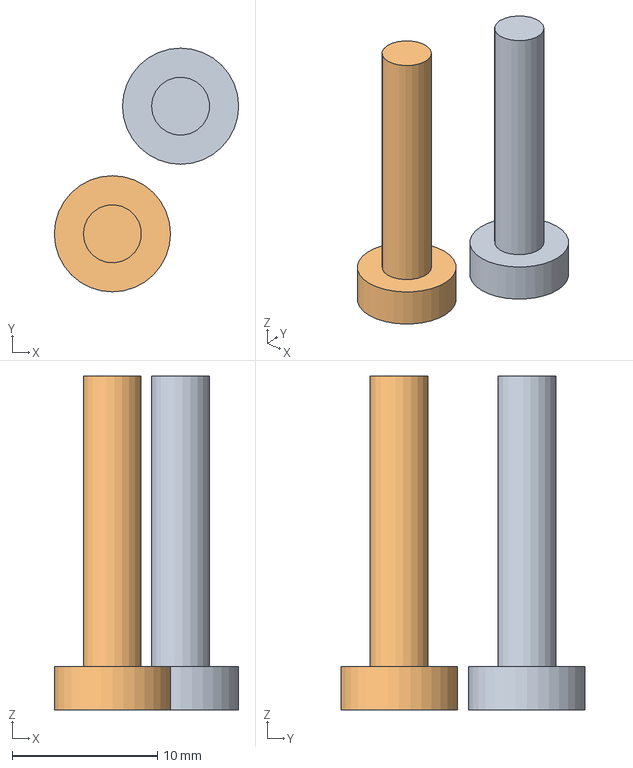
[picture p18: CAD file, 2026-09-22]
print-projects/spark-rack/prototype/modular-spark-rack-pla-pin-trial-brim5.3mf
12.7 x 16.8 x 23.0 mm
locking_pin.stl x 2

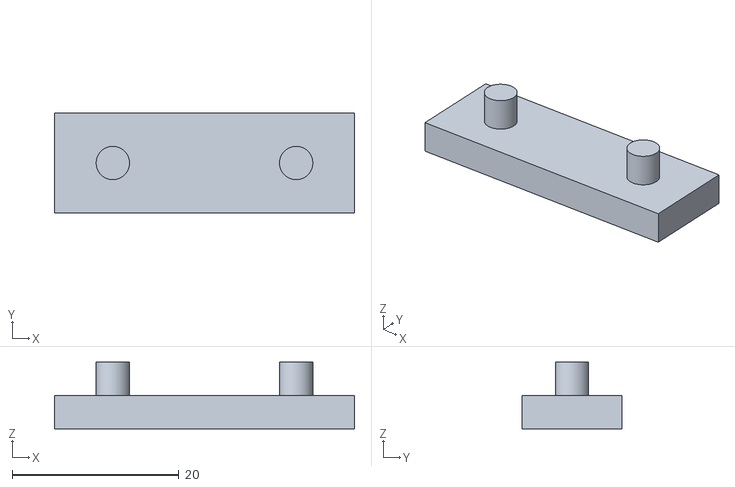
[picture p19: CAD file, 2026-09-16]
exports/adapter-stand/stl/join_clip.stl
36.0 x 12.0 x 8.00

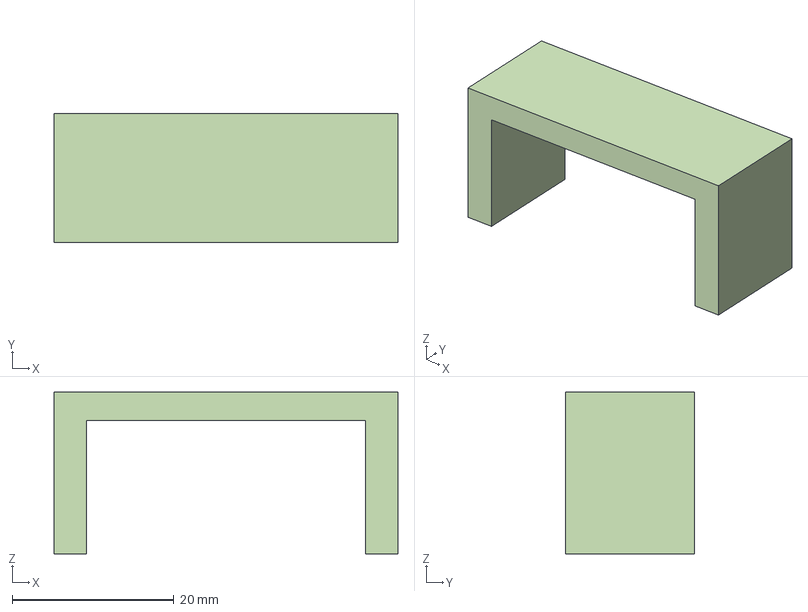
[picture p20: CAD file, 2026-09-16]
exports/freecad/parts/bridge_clip.step
42.6 x 16.0 x 20.0 mm

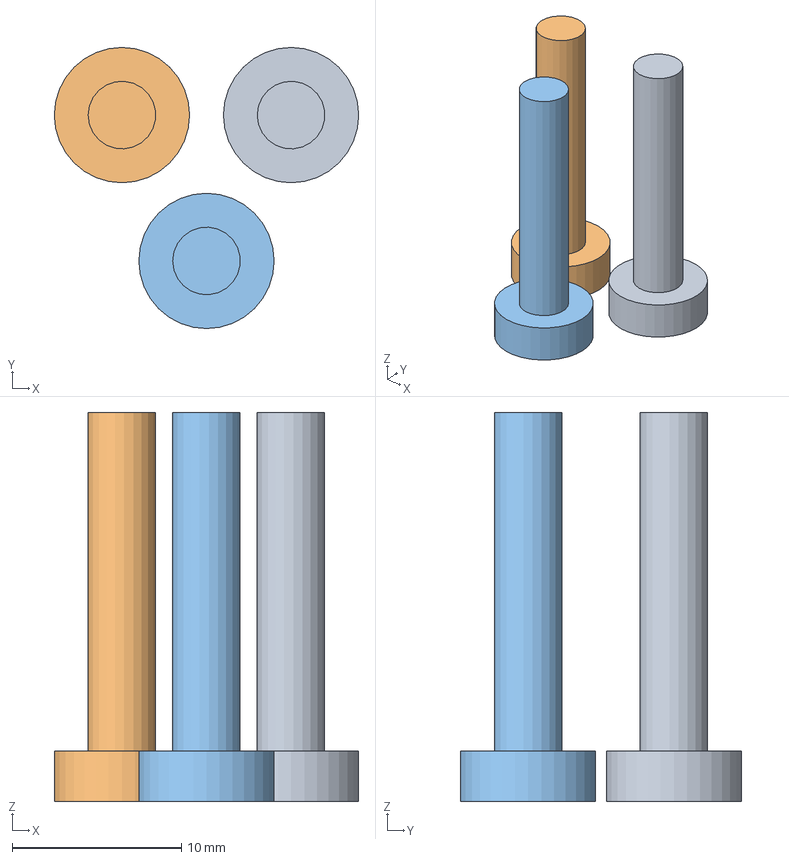
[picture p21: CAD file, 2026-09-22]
print-projects/spark-rack/prototype/modular-spark-rack-pla-pins-3-brim5.3mf
18.0 x 16.6 x 23.0 mm
locking_pin.stl x 3

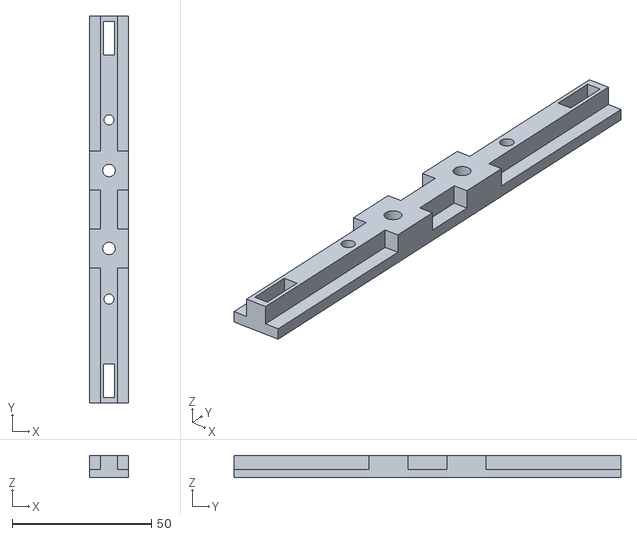
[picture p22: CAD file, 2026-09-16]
exports/adapter-stand/stl/rail.stl
14.0 x 139.0 x 8.00

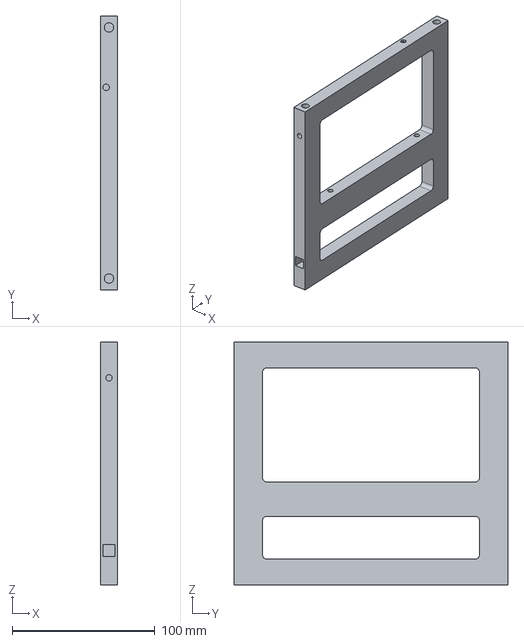
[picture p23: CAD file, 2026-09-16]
exports/freecad/parts/side_R.step
12.0 x 192.0 x 170.0 mm

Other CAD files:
exports/freecad/DGX-SPARK-RACK-v1.step
print-projects/spark-rack/prototype/modular-spark-rack-pla-fit-tests.3mf
exports/freecad/parts/side_L.step
print-projects/spark-rack/prototype/modular-spark-rack-pla-frame-without-pins.3mf
archive/print-projects/spark-rack/pla-frame-one-unit.3mf
archive/print-projects/spark-rack/rack-layout-before-pla-20260921.3mf
archive/spark-rack-fcstd-v1/generated/DGX-SPARK-RACK-v1.step
archive/spark-rack-fcstd-v1/generated/parts/crossbar.step
archive/spark-rack-fcstd-v1/generated/parts/fan_cassette.step
archive/spark-rack-fcstd-v1/generated/parts/fit_coupon_020.step
archive/spark-rack-fcstd-v1/generated/parts/fit_coupon_030.step
archive/spark-rack-fcstd-v1/generated/parts/fit_coupon_040.step
archive/spark-rack-fcstd-v1/generated/parts/locking_pin.step
archive/spark-rack-fcstd-v1/generated/parts/side_L.step
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

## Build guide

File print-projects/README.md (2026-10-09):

# 印刷設定

このフォルダの3MFはBambu Studioの印刷設定です。**形状の正本は [../models/](../models/) にあります。** 設計変更を3MFだけで完結させません。

本体ラックの保存ファイルには`modular-spark-rack-`を付け、従来の連結式ラック用と分かる名前にしました。内容は変更していません。[4台専用ラック](../models/spark-rack/docs/4台専用ラックの設計条件.md)用の印刷設定は、形状を決めてから作成します。

| 本体ラック用ファイル | 用途 |
|---|---|
| [modular-spark-rack-pla-fit-tests.3mf](spark-rack/prototype/modular-spark-rack-pla-fit-tests.3mf) | 接合と金具の試験片 |
| [modular-spark-rack-pla-frame-without-pins.3mf](spark-rack/prototype/modular-spark-rack-pla-frame-without-pins.3mf) | 側板2枚・支持棒3本。ピンは別印刷 |
| [modular-spark-rack-pla-pin-trial-brim5.3mf](spark-rack/prototype/modular-spark-rack-pla-pin-trial-brim5.3mf) | 固定ピン2本、外側5mmブリム |
| [modular-spark-rack-pla-pins-3-brim5.3mf](spark-rack/prototype/modular-spark-rack-pla-pins-3-brim5.3mf) | 追加ピン3本、外側5mmブリム |
| [modular-spark-rack-pla-fan-cassette.3mf](spark-rack/prototype/modular-spark-rack-pla-fan-cassette.3mf) | 140mmファン用保持部1個 |

いずれもPLA仮組み用の記録です。現在のプリンター・プレート・素材割り当てを確認してから印刷します。旧混在配置とバックアップは [../archive/print-projects/](../archive/print-projects/) に分けました。この一覧は手調整済みの保存ファイルです。3モデルの自動生成3MFは下記の別フォルダに出力します。

## 試作と本番の区分

各モデルの `prototype/` が試作用、`production/` が本番用です。既存3MFはすべてPLA試作用へ移動しました。本番用3MFはまだありません。自動生成履歴も `prototype/generated/` に移しています。アーカイブ内の過去データは履歴として保全します。

## 自動生成する

`mise run 3mf:prototype:<モデル名>` でCADから再生成し、部品別3MFを `<モデル名>/<用途>/generated/<実行ID>/` に出力します。既存の手調整済み3MFは上書きしません。生成物はGit管理対象外、用途は `prototype` または `production` です。本番用は `mise run 3mf:production:<モデル名>` で生成しますが、素材・条件が未設定なら停止します。共通の設定は `profiles/` で管理します。[操作と検査の範囲](../docs/タスクランナー.md)を参照してください。

## ライセンス

[Apache License 2.0](../LICENSE)

Copyright 2026 IDEO PLUS LLC

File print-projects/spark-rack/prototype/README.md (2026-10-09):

# 試作用印刷設定

`modular-spark-rack-`で始まる保存ファイルは、従来の連結式ラック用です。4台専用ラック用の印刷設定はまだ作成していません。

PLAで仮組みするための3MFです。本番用ではありません。`mise run 3mf:prototype:spark-rack` で `generated/<実行ID>/` に生成します。採用した手調整済み3MFはこのフォルダへ別名保存します。[操作手順](../../../docs/タスクランナー.md)を参照してください。

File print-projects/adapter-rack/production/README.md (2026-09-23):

# 本番用印刷設定

本番用3MFはまだありません。素材と印刷条件を決定し、`print-projects/profiles/production/adapter-rack.json` を設定してから生成します。[設定方法](../../../docs/タスクランナー.md)を参照してください。

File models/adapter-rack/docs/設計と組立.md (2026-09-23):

# ACアダプターラックv2：1台ずつ縦横に増設する

DGX Sparkの純正電源を本体ラックとは別に置く、黒い樹脂フレームの設計試作です。1台分の収納部を上下・左右に連結し、最大2段×2列の4台構成までCADで確認します。手持ちのNoctua NF-A12x25 G2を使うため、**縦2台までを120mmファン1基で送風する構成**を基本案にしました。必要な冷却性能を満たすかは実測で判断します。

まず「配置」「生成」「接合試験」の順に読んでください。部品表と組立手順は、試作する段階で参照できます。造形や組立で合わない箇所は、この作業の会話に部品名と写真・寸法を伝えてください。

## 配置：配線は左右、風は前から後ろへ

アダプターのAC入力とUSB-Cケーブルを左右のX方向へ向け、ファンは手前の−Y側に配置します。空気はアダプターの広い面に沿って後ろへ流す想定です。各端子側には30mmの配線余白を設計上確保しました。これはメーカー指定の離隔やケーブル曲げ半径ではありません。端子の実位置・ケーブル形状は実物で確認します。

収納部は幅164×奥行148×高さ76mmです。共通ドックとケースは外側へ張り出します。構成別のラック外形は生成した検査結果、ケース装着状態は[取付検査](../../fan-controller/docs/ラックへの取り付け.md)のFCStdで確認してください。

1台・横2台・縦2台・2段2列の4構成を用意しています。1段だけの構成でも同じファン保持板を使うため、ファン部分は収納部より上へ張り出し、全高は144mmになります。2段にするとファン中心が段の境界に来ます。ファンは下段の前柱4か所にねじで固定し、上段の有無で付け替える必要はありません。

前面のファンを外さずに電源を取り出せるよう、後方への水平な取り出し経路を空けています。取り出す前に配線と保持バンドを外してください。

## 生成：Pythonを正本としてFCStdとSTLを出す

FreeCADで `models/adapter-rack/source/run_adapter_rack.FCMacro` を実行します。出力先は `build/adapter-rack/<実行ID>/` です。既存の本体ラック、旧スタンド、印刷用3MFは上書きしません。

- 設計寸法：`models/adapter-rack/source/adapter_rack_parameters.py`
- スケッチ・加工・配置：`models/adapter-rack/source/freecad_adapter_rack.py`
- CAD検査：`models/adapter-rack/source/validate_adapter_rack.py`
- 生成・出力：`models/adapter-rack/source/build_adapter_rack.py`
- 購入品の根拠：`models/adapter-rack/reference/components.json`

出力フォルダには履歴付きFCStd、4構成のSTEP・画像、部品別STEP・STL、`validation.json`、`stl_validation.json`、ソースと出力のハッシュを記録した `manifest.json` が入ります。FCStdの初期表示は縦2台です。FreeCADのPythonコンソールで `show_layout(doc, columns=2, rows=2)` を呼ぶと4台表示へ変更できます。関数は `freecad_adapter_rack` モジュールにあります。

寸法表で試した値を採用するときは、Pythonへ戻して再生成します。最大2段×2列を超える構成は今回の検査対象外です。

## 接合試験：大きな部品より先に隙間を選ぶ

新しい接合部の既定値は片側0.30mmです。本体ラックで0.20mmが合った結果は参考にしますが、今回は支持棒の形と固定方法が異なります。

最初に `fit_coupon_020`、`fit_coupon_030`、`fit_coupon_040`、`beam_coupon` と `locking_pin` を各1個印刷します。短い棒の穴が端に近い側を試験片へ差し込み、ピンを通してください。手で抜き差しでき、大きなガタや白化がない隙間を選びます。採用値を `FitClearance` に反映してから側枠などを再生成します。

固定ピンは本体ラック用とは別部品です。今回の支持棒固定ピンは径4mm、軸長20mm、頭を含む全長23mmです。外見が似ていても、穴との適合を確認して区別してください。上下位置決めピンは径6mm・長さ18mmです。

## 印刷する部品

| 部品 | 1台 | 縦2台 | 横2台 | 2段2列 |
|---|---:|---:|---:|---:|
| side_L / side_R | 各1 | 各2 | 各2 | 各4 |
| support_beam | 2 | 4 | 4 | 8 |
| locking_pin | 4 | 8 | 8 | 16 |
| stack_pin | 0 | 4 | 0 | 8 |
| stack_strap | 0 | 2 | 0 | 4 |
| join_bridge | 0 | 0 | 2 | 4 |
| fan_plate | 1 | 1 | 2 | 2 |
| accessory_plate | 1 | 1 | 2 | 2 |

表は列ごとにファン1個とファンコン用ドック1個を付ける構成です。2列なら左右の外側へ取り付けます。ケースは別モデルから生成します。試験片4種類は表に含めていません。STLは13種類です。色は本番のフレームを黒、ファンをベージュ／ブラウンとします。CADの緑色は連結部品の識別用で、印刷色の指定ではありません。

STLは造形方向と原点をそろえて出力します。左右の側枠と接合試験片は差込口を上に、支持棒は平置き、固定ピンは頭を下にしています。ファン保持板・上下保持板・ファンコン取り付け面は平置き、横クリップは橋の面を下にします。横穴はスライサーでブリッジやサポートを確認してください。

細いピンとクリップは大きなフレーム部品と別プレートにし、ピンには成功実績のある外側5mmブリムを候補とします。今回のv2については、スライスと実際の造形はまだ行っていません。PLAで仮組みし、本番材へ替えるときはその材料で接合試験をやり直します。

## 金具とファンを用意する

ファンは120mm角、取付穴ピッチ105mm、防振パッド込み厚さ27mmのNF-A12x25 G2 PWM PPA/PPBが基準です。仕様は[Noctua公式](https://www.noctua.at/en/products/nf-a12x25-g2-pwm-sx2-pp/specifications)で確認しています。画像ではファンの外枠と穴だけを参考形状として表示し、羽根・ケーブル・ワイヤーガードは省略しています。

| 購入部品 | 縦2台 | 2段2列 | 用途 |
|---|---:|---:|---|
| 120mm PWMファン | 1基 | 2基 | 列ごとの送風 |
| 対応する120mmワイヤーガード | 1枚 | 2枚 | ファン前面 |
| ファン固定具 | 4か所分 | 8か所分 | ファン・ガード・保持板の固定 |
| M4×25ねじ | 8本 | 16本 | ファン保持板と上下保持板 |
| M4×25六角穴付きボルト | 2本 | 4本 | ファンコン用共通ドック |
| M4ナット | 10個 | 20個 | 上のラック固定ねじ用。ファン固定用は別 |
| M3×12の90度皿ねじ／M3ナット | 各2 | 各4 | ケース外側の取付耳とドックの固定 |
| 電源保持バンド・配線用バンド | 必要数 | 必要数 | 支持棒の長穴などに通す |

これらは設計上の購入寸法で、組立実証はまだです。共通ドックのM4ねじ頭は径8mm以下・高さ4mm以下で、座ぐりに沈めます。ドックのM3ナットは裏面の六角穴、ラック側のM4ナットは側枠の内側で保持します。詳細は[ケース取付手順](../../fan-controller/docs/ラックへの取り付け.md)を参照してください。

ファン固定は保持板厚4mmにガードとファンの厚さを加えて選びます。付属ねじが届くとは限りません。通しボルト方式ならM4×40を候補に、実際のガード・ワッシャー・ナットの厚さと突き出しを確認します。本体ラック用に購入したM4×60とは長さが異なります。

## 組立：下段から固定して増設する

1. 左右側枠の差込口へ支持棒2本を入れ、上から固定ピン4本を通します。
2. 電源の代わりにダミー荷重を載せ、支持棒・差込部に変形がないか確認します。
3. 縦に増設するときは、四隅の穴へ上下位置決めピンを差し、上段を載せます。左右外面の上下保持板をM4ねじとナットで留めます。荷重は側枠の接触面で受けます。
4. 横に増設するときは、隣り合う側枠の前後2か所へ横連結クリップを差し込みます。2段なら各段に2個使います。
5. ファンとガードを保持板へ取り付け、保持板を下段前柱の4か所にM4ねじで固定します。ファンの風向表示で前から後ろへの送風を確認します。
6. 電源を後ろから差し入れます。AC入力とUSB-Cを左右へ向け、支持棒の長穴を使って必要に応じて保持バンドを通します。配線には余裕を残します。

上下位置決めピンと横クリップは、位置をそろえるための部品です。横クリップには持ち上げに対するロックがありません。機器を載せたまま運搬しません。積み重ね試験では、上段電源の重量だけでなく上段フレーム・ファンなどの重量も下段へかかる条件で確認します。

## ファンコンケースを共通ドックで固定する

ユーザー所有の温度センサー付き基板型コントローラーを、ファン1個につき1個使います。`models/fan-controller/` のケース底部の取付耳を、M3穴ピッチ92mmの共通ドックへ固定します。ラックの既存M4穴ピッチ28mmを使うので、側枠の穴は変更不要です。

120mm×2用はファンコン2個・ACアダプター1個・DC電源二股ケーブル1本を使用し、140mm×2用の同構成とは分けます。各ファンをそれぞれの温度センサーで独立制御します。[ケースの取付配置・部品表](../../fan-controller/docs/ラックへの取り付け.md)にまとめています。

## CADで確認した範囲と次の試作

各構成について、閉じたソリッド、スケッチの完全拘束、部品同士の干渉、左右の配線余白、後方への電源取り出し経路、上下側枠の接触面を検査します。電源の寸法を105×105×38mmへ変えたケースと、元の値に戻したケースも検査し、保存後にFCStdを再読込します。

ケース・取付ボルト・ナットは別の取付検査モデルに含めます。金具のねじ山、コネクターとケーブルの実形状は省略します。CADで干渉がないことは、耐荷重・耐熱・冷却性能の確認とは別です。まず専用の接合試験片、その後1台分、最後に縦2台の順で試作してください。電源の温度はファン停止時と運転時を同じ室温・負荷で比較して判断します。

用語：収納部は電源1台を支えるフレーム、支持棒は電源底面を支える2本の棒、上下保持板は上下段をねじでつなぐ板、横連結クリップは隣の側枠同士の位置をそろえる部品です。

更新日：2026年9月22日。

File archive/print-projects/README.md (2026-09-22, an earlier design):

# 採用しなくなった印刷配置

以下は履歴として保管します。現在の設定は [../../print-projects/](../../print-projects/) にあります。

| ファイル | 退避理由 |
|---|---|
| [pla-frame-one-unit.3mf](spark-rack/pla-frame-one-unit.3mf) | ピンとフレームを混在させた配置。ピンの失敗が他部品に波及したため、分離した配置へ変更 |
| [rack-layout-before-pla-20260921.3mf](spark-rack/rack-layout-before-pla-20260921.3mf) | PLA試作設定を作る前の配置バックアップ |

3MF自体の内容は変更していません。

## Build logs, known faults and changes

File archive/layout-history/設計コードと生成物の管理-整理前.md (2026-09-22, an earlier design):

> 整理前の記録です。現在の手順は[正本と生成物の管理](../../docs/設計コードと生成物の管理.md)を参照してください。

# 設計コードと生成物の管理

設計の正本（SSoT）はPythonの設計コードと寸法定義です。FCMacroは実行入口とし、FCStd・STEP・STLはそこから生成します。

## 対象と移行状況

| 対象 | 正本 | 現在の状態 |
|---|---|---|
| アダプタースタンド | `scripts/freecad_adapter_stand.py`、`scripts/freecad_features.py`、`scripts/adapter_stand_parameters.py` | コードから新規生成・検査・出力できる |
| アダプターラックv2 | `scripts/freecad_adapter_rack.py`、`scripts/adapter_rack_parameters.py` | 縦横連結、列ごとの120mmファン、ケース用取り付け面を生成する |
| 本体ラックv1 | `DGX-SPARK-RACK-FREECAD-v1.FCStd` | 旧生成コードは削除済み。コード移行前の例外として保全する |
| ファンコンケース | 未特定 | 既存設計の入手先を確認してから生成経路に組み込む |

本体ラックの次版で採用する片側0.20mmの接合隙間は、まだ本体ラックv1へ反映していません。既存ラックv1のSTLは片側0.30mmのままです。アダプターラックv2の縦横連結・120mmファン対応は別の生成経路で追加しました。アダプターラックの接合部は別設計なので、本体ラックの試験結果をそのまま転用せず、専用試験片で隙間を選びます。

## ファイルの責務

- `adapter_stand_parameters.py`：生成に使う寸法値・式・説明。寸法変更はここを編集する。
- `freecad_adapter_stand.py`：部品のスケッチ、加工、組立配置を定義する。
- `freecad_features.py`：拘束付きスケッチや加工の共通処理。
- `design/adapter-stand/adapter_spec.json`：購入品の参照実測値と出典。設計寸法そのものの変更先ではない。
- `build_adapter_stand.py`：新規文書の作成、出力先の選択、検査と来歴の記録をまとめる。
- `export_adapter_stand.py`：渡された文書を検査してFCStd・STEP・STL・画像へ出力する。既に開いている別文書を入力にしない。
- `run_adapter_stand.FCMacro`：上記を呼ぶ薄い入口。同じFreeCADセッション内でも編集したモジュールを読み直す。

## 再生成

アダプターラックv2は `scripts/run_adapter_rack.FCMacro` から `build/adapter-rack/<実行ID>/` に生成します。検査は `validate_adapter_rack.py`、出力処理は `build_adapter_rack.py` です。[v2ガイド](../../models/adapter-rack/docs/設計と組立.md)に構成と印刷部品を記載しています。以下は保全した旧スタンドの生成手順です。

FreeCAD GUIで `scripts/run_adapter_stand.FCMacro` を実行します。毎回新しい文書を作り、`build/adapter-stand/<日時>-<識別子>/` に出力します。既存の出力フォルダを明示指定した場合は上書きせずエラーになります。

FreeCADのPythonコンソールでは、次の方法でも実行できます。

```python
from pathlib import Path
import sys

root = Path("/このリポジトリの絶対パス")
sys.path.insert(0, str(root / "scripts"))
from build_adapter_stand import build
output = build()
```

通常のPython単体ではFreeCADモジュールを読み込めません。FreeCAD GUIと、そのバージョンに対応するPython環境が必要です。`build(render_images=False)` は画像出力だけを省略します。現在のモデルは表示属性も生成するため、この指定でもFreeCAD GUIモジュールの初期化が必要です。

## 出力と合格条件

| 出力 | 内容 |
|---|---|
| `DGX-SPARK-ADAPTER-STAND.FCStd` | 履歴・寸法式付きモデル。初期表示は2台 |
| `assembly-two-units.step` | 参考アダプターを含む2台組立 |
| `step/*.step` | 4種類の印刷部品。STLと同じ造形方向・原点 |
| `stl/*.stl` | 4種類の印刷部品。単位mm、各軸の最小座標0 |
| `two_units.png`、`four_units.png`、`stand_only.png` | 通常実行時の配置画像 |
| `validation.json` | 拘束、ソリッド、干渉、配線余白、寸法変更と復元、保存後の再読込 |
| `stl_validation.json` | STLの閉じた形状、接続成分、体積、外形 |
| `manifest.json` | 成功状態、FreeCAD版、元コードと出力のSHA-256 |

`manifest.json` は全検査の成功後だけ作成します。途中で失敗した実行フォルダは診断用で、印刷に使いません。ファイルのハッシュは来歴の確認用です。FreeCADやSTEPに日時等が入るため、同じコードでもバイナリが毎回一致する保証はありません。再現性はパラメーター、部品体積、寸法、ソリッド数などの幾何情報でも確認します。

## 変更の流れ

1. 設計コードと寸法定義を編集する。
2. マクロで再生成し、検査結果と形状を確認する。
3. 接合試験片や必要な部品だけを印刷し、結果を記録する。
4. 採用するコードを保存する。生成物を配布する場合は同じ実行のmanifest・検査結果を添える。

生成したFCStdの寸法表は試行のために編集できます。ただしGUIだけの変更は次回生成で再現されません。採用する値は必ずPythonの寸法定義へ戻して再生成します。

`exports/` とルートの既存FCStdは従来版の保存物です。新しい生成処理から自動で置き換えません。3MFは造形方向・個数・フィラメント・ブリムなどの印刷工程の記録として保持し、STLの更新後は必要に応じて作り直します。

## 基盤整備時の確認

2026年9月22日、FreeCAD 1.1.3で2回生成し、2台・4台構成の検査結果、寸法変更と復元、再読込結果、STLハッシュの一致を確認しました。従来版との組立寸法・部品体積も一致しています。配置画像の生成、ソースと出力のmanifestハッシュ、既存出力への上書き拒否も確認しました。

検証用にFreeCAD付属PythonへGUIを組み込んだ実行では、生成成功後のQt終了処理でクラッシュが起きたため、検証プロセスでは文書を閉じてから即時終了しました。この回避処理は設計コードには含めていません。通常の入口はFreeCADアプリ内のFCMacroです。offscreenプラットフォームでのGUI初期化も、この環境では動作しませんでした。

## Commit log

2026-09-06 feat(rack): preserve validated Fusion master and print assets
    [DGX-SPARK-RACK-FUSION-v1.f3d, DGX-SPARK-RACK-FUSION-v1.step, bar_coupon.stl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]
2026-09-06 test(cad): record FreeCAD migration fidelity and runtime limits
    [DGX-SPARK-RACK-STEP-evaluation.FCStd]
2026-09-06 feat(freecad): add editable crossbar with migration checks
    [crossbar-native.FCStd, crossbar-native.step, crossbar-native.stl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]
2026-09-06 feat(freecad): add parametric sideplate with geometry verification
    [fusion_sideplate_reference.step, side-L-native.FCStd, side-L-native.step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]
2026-09-06 feat(cad): generate complete FreeCAD rack from Fusion geometry
    [DGX-SPARK-RACK-FREECAD-v1.FCStd, bar_coupon.step, bridge_clip.step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]
2026-09-06 feat(freecad): add provisional open adapter stand
    [DGX-SPARK-ADAPTER-STAND-v1.FCStd, join_clip.stl, locking_pin.stl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]
2026-09-16 chore(cad): remove Fusion and comparison-only assets
    [DGX-SPARK-RACK-FUSION-v1.f3d, DGX-SPARK-RACK-STEP-evaluation.FCStd, DGX-SPARK-RACK-v1.step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]
2026-09-16 fix(stand): use published DGX Spark adapter dimensions
    [DGX-SPARK-ADAPTER-STAND-v1.FCStd, join_clip.stl, locking_pin.stl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]
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2026-09-22 chore(print): preserve PLA prototype slicer projects
    [pla-fan-cassette.3mf, pla-fit-tests.3mf, pla-frame-one-unit.3mf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]
2026-09-22 refactor(cad): separate model sources, print projects, and archives
    [DGX-SPARK-ADAPTER-STAND-v1.FCStd, DGX-SPARK-RACK-FREECAD-v1.FCStd, DGX-SPARK-RACK-v1.step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]
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2026-09-23 feat(print): separate prototype and production workflows
    [fan-controller-blue-pla-body-lid-20260923.3mf, pla-fan-cassette.3mf, pla-fit-tests.3mf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]
2026-09-23 fix(cad): correct USB opening and replace fragile lid retainers
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2026-09-23 fix(cad): keep mounting screw heads clear of connector access
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2026-09-23 fix(cad): protect mating openings during edge finishing
2026-10-09 chore(archive): preserve prior rack designs before the four-node redesign
    [modular-spark-rack-pla-fan-cassette.3mf, modular-spark-rack-pla-fit-tests.3mf, modular-spark-rack-pla-frame-without-pins.3mf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]
2026-10-11 fix(controller): correct knob opening from prototype measurements
2026-10-12 feat(rack): integrate fixed supports and compare dedicated switch bays
2026-10-12 docs(rack): record redesign assumptions and switch placement decisions
2026-10-12 chore(archive): preserve unmerged switch-support and independent rack proposals
    Both branches were built on frames the fixed rack has replaced, so merging
    them would revive superseded geometry and conflict with main. Keep their
    added files, the switch-support patches, and hash-checked manifests under
    archive/ so the branches can be deleted without losing history.
2026-10-12 docs(rack): record that the switch and breakout cables are ordered
    main still said the purchase was unconfirmed, while the only order report
    lived on an unmerged branch. The user confirmed both items are ordered and
    not yet delivered; the breakout cable count remains unknown.
2026-10-12 fix(rack): show the breakout cable order count apart from the required count
    Next to "ordered", the overview only showed the required count of two
    cables, which reads as the ordered count. Show the ordered count on its
    own line and say it is not yet provided while the record is null.
2026-10-12 docs(rack): record the CRS812 mounting methods from the official manual
    The upper switch bay needs a support interface before the switch arrives.
    The official manual describes front ears with rear support ears, or rubber
    feet on a desk, but not ear width, hole positions, mass, airflow, or which
    panel holds the power supplies and fans. Record what is stated and keep the
    rest null so the bay design does not invent those values.
2026-10-12 feat(rack): generate an upper switch bay that shares the top frame
    Stacking a dedicated bay on the 560mm frame reaches 668mm and leaves the
    old top frame and the space above the upper Spark exchange path unused.
    Moving the top frame above the bay and seating its floor in the side
    frames keeps the Spark levels and power compartment, keeps a front path
    over the upper fan carriers for switch-side parts, and needs 618mm.
    The switch sits on two trays that slide out the rear on floor guides and
    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
2026-10-12 docs(rack): explain the shared-frame upper switch bay and its trade-offs
    The comparison doc recommended an upper bay but left support, fixing and
    height open. Record why the shared-frame option is recommended over
    stacking (668mm) and the lowest floor (599mm), how the load reaches the
    side frames, which unknowns would change the choice, and the 23% shape
    volume increase so it can be revisited once the switch is measured.
2026-10-12 docs(print): record PAHT-CF black as the production material
    The production profile was unregistered with no material decided, while
    appearance and heat near the top-mounted switch depend on it. The user
    chose black PAHT-CF; record it with the manufacturer data found so far.
    Print conditions are still open, so no production profile is created and
    production generation keeps stopping instead of falling back to PLA.
2026-10-12 docs(rack): record the remote console devices and what is still unknown
    The rack now has to hold a GL.iNet Comet Pro and a KCEVE four-input
    HDMI/USB switcher. Record the Comet Pro values from GL.iNet's datasheet,
    including its 0-40 C operating range, and keep the switcher's size, power
    and port faces null because its product and manual pages could not be
    read. The shelf uses a provisional envelope until the switcher is measured.
2026-10-12 feat(rack): add a mid-level shelf for the remote KVM and switcher
    Removing the central switch rails in the upper-bay design left the space
    between the Spark rows empty and open at the front. A shelf seated in the
    side frames now carries the Comet Pro at the front and the four-input
    switcher at the back, near the Spark rear ports.
    Seating the Comet Pro right behind the front would leave 0.25mm under the
    upper fan rail, so it sits behind the lower fans and is shown through a
    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
2026-10-12 docs(rack): explain the remote console shelf and its open items
    Record how the shelf height follows from the cable storage and the lower
    fan carriers, why the Comet Pro sits at the front and the switcher at the
    back, and what must be measured before the layout is final: the switcher
    size and power, Spark HDMI/USB port positions, hotkey switching through
    the Comet Pro, AC outlets, and the mid-level temperature.
2026-10-12 fix(rack): address review findings on the upper bay and accessory shelf
    - Fuse the accessory shelf band before the side-frame bands are built.
    It was appended after fusing, so only 4.75mm of full-thickness frame
    sat under the shelf bearing instead of the intended 6mm.
    - Skip the switch front-service check and the switch-on-tray contact in
    the ring phase, where the bay has no switch, so validation no longer
    fails with an index or key error.
    - Build the stacked comparison from the same bay parameters as the
    shared-frame rows, so changed hand space raises all three heights.
    - Record panel screws through both the panel flange and the shelf band.
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2026-10-12 feat(rack): offer a honeycomb grille for the upper-bay front and top
    The upper-bay finish uses vertical slots on the fan grilles, the
    mid-level panels, the top-bay covers, the bottom fillers and the lid.
    A honeycomb face is a common alternative, so make it a switchable
    pattern rather than a separate design to compare against.
    Add `--grille honeycomb` to the upper-bay build and a matching mise
    task. Holes are regular hexagons, 10mm across flats with 1.6mm walls:
    the walls are four 0.4mm nozzle widths and the 11.5mm corner-to-corner
    span keeps a 12mm finger out. Panels and the lid only open hexagons
    that fit whole inside the slotted area, so no thin broken walls are left
    at the edges. The fan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
2026-10-12 fix(rack): carry the honeycomb grille to the side frames and power fan plates
    The honeycomb option left the side-frame vent windows and the side power
    fan plates with their slots and vertical bars, so the variant was not
    honeycomb throughout.
    Cut the side-frame vents as hexagons through the full section, within
    the same zones and margins as the slotted windows, so the shelf, floor
    and band supports stay solid. Clip the power fan plates' hexagons to
    the 114mm opening as on the front fan carriers; they keep 73.8% of the
    opening. Hexagons can now run across the frame as well as front to back
    and top to bottom.
    The side frames are the rack's structural faces. With the honeycomb
    the outer skin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
2026-10-19 fix(rack): align canonical sources and validate body-frame interfaces
2026-10-19 fix(rack): preserve the full direction in assembly collision sweeps
